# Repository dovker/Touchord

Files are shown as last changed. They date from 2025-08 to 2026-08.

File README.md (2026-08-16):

# Touchord
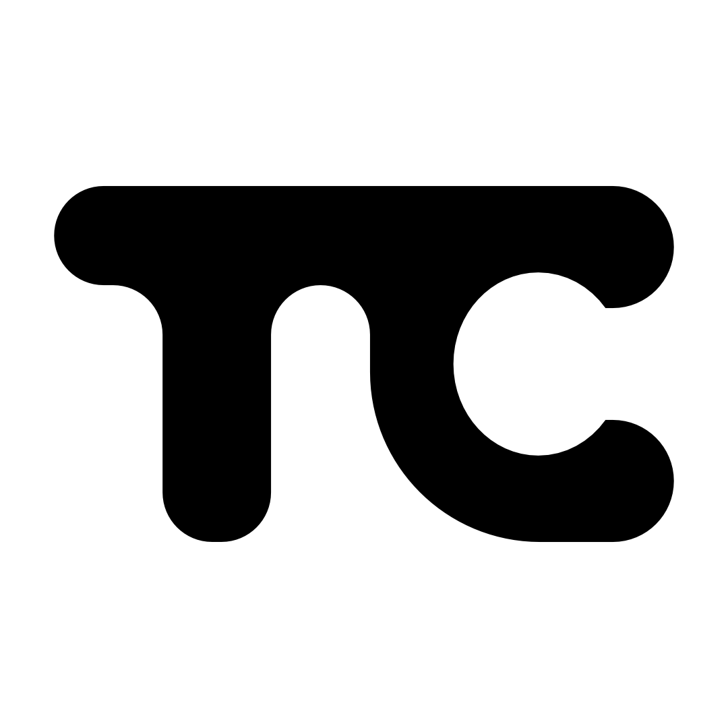
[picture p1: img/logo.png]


Touchord is an open source chord-generating MIDI controller featuring a touch bar interface. It is designed for musicians seeking versatile chordal playing and performance options and for makers looking for a highly modifyable product with a realistic and fun use.

## [TOUCHORD DIY KIT PRE-ORDERS](https://daugdara.com/products/touchord-diy-kit)

## Motivation

Making music without formal training is hard. Learning theory takes time, and when the goal is to create and express ideas quickly, it can feel tedious. Chord progressions and harmony are crucial yet difficult to master; exploring by ear works, but entering complex chords on guitar or piano is slow. That is where chord‑generating synths and MIDI controllers help.

**Why not buy an existing similar device?** Many are closed‑source and built by unestablished companies with limited support histories. When projects are abandoned or parts become unavailable, devices turn into e‑waste.

Touchord addresses these problems. Components are common, 3D‑printable, or manufacturable at a reasonable cost, thus repairs and replacements remain feasible. Open development also streamlines bug fixes and issue tracking because contributors can help accelerate software improvements. And if we for some reason stop developing new updates or cannot contribute anymore, community still remains along with the source code and all the production files, keeping the project alive.

## Licensing and Legal Notice

**Copyright © 2026 MB Daugdara. All rights reserved.**

**Trademarks:**
- Touchord™ is a trademark of MB Daugdara
- Touchord™ logo is a trademark of MB Daugdara

**Intellectual Property:**
- The Touchord name and logo are the exclusive property of MB Daugdara
- Firmware is licensed under GNU General Public License v3.0
- The 3D model design files and PCB Files are licensed under CERN-OHL-S-2.0
- The license does not grant rights to use the company name or logo

**Restrictions:**
- You may not use the company name or logo to endorse derivative commercial works
- You must include this notice when distributing modified versions
- See LICENSE file for full CERN-OHL-S-2.0 terms

## Features

- **Three Operating Modes:**
  - **Strum Mode:** Harp style playing for plucked synths.
  - **Omni Mode:** An omni-chord style play mode mimicking the strumming of an omnichord.
  - **Composer Mode:** Allows adjustment of chord qualities directly via the touch bar for chord customization.
  - **Perform Mode:** Uses the touch bar’s pressure sensitivity for expressive live performances.
  - **Drum Mode:** A simple mode with chromatically mapped keys and the touch bar controlling velocity.

- **Chord Layout:**
  - Each key corresponds to a chord degree in a musical key.
  - Supports custom musical keys and customizable chords on each key.

- **Hardware:**
  - Uses the RP2350 microcontroller chip.
  - Programmed with the PicoSDK in C.
  - Cherry MX style mechanical switches.
  - 6 control buttons.
  - 7 chord keys sized 3u, equipped with 3u plate-mounted stabilizers for enhanced stability.
  - Touch bar: [Trill Bar by Bella](https://bela.io/products/trill/) ([GitHub](https://github.com/BelaPlatform/Trill)) providing multi-touch and pressure sensing.
  - Display: Standard 0.96" 128x64 OLED SSD1306 screen.

- **Enclosure:**
  - Combination of 3D printed carbon fiber reinforced PETG base and CNC machined aluminum top.
  - Optionally, the top can also be fabricated via 3D printing.

- **Connectivity:**
  - USB Type-C MIDI support.
  - TRS MIDI support (User switchable in software):
    - **TRS Type A (Standard MIDI TRS)**
    - **TRS Type B (Roland TRS MIDI)**

---

## Contribution

Check `CONTRIBUTING.md` for more info.

### AI Usage

AI usage on Bug Fixes and Code Auditing is welcome, if done with proper testing, cleanup and no blind trust. Please disclose AI usage in Pull Requests.
Features are better left for humans to write.

---

## Showcase

Showcase video (https://www.youtube.com/watch?v=dFS27xT5Rgg)
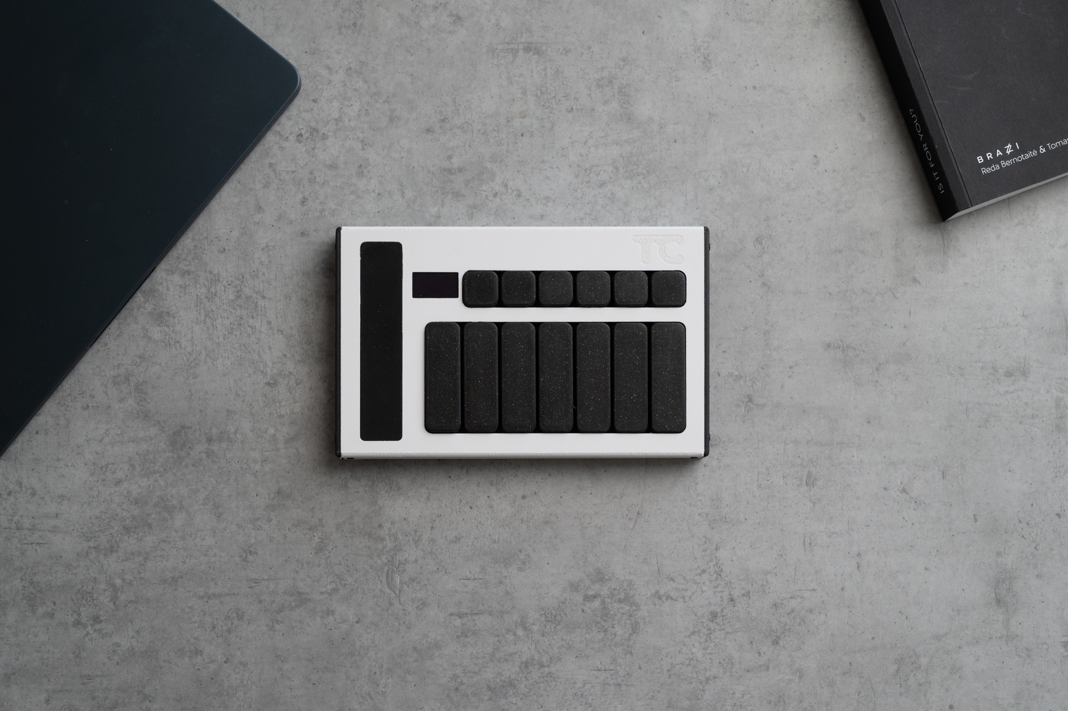
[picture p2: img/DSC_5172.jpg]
Touchord On a grander scale

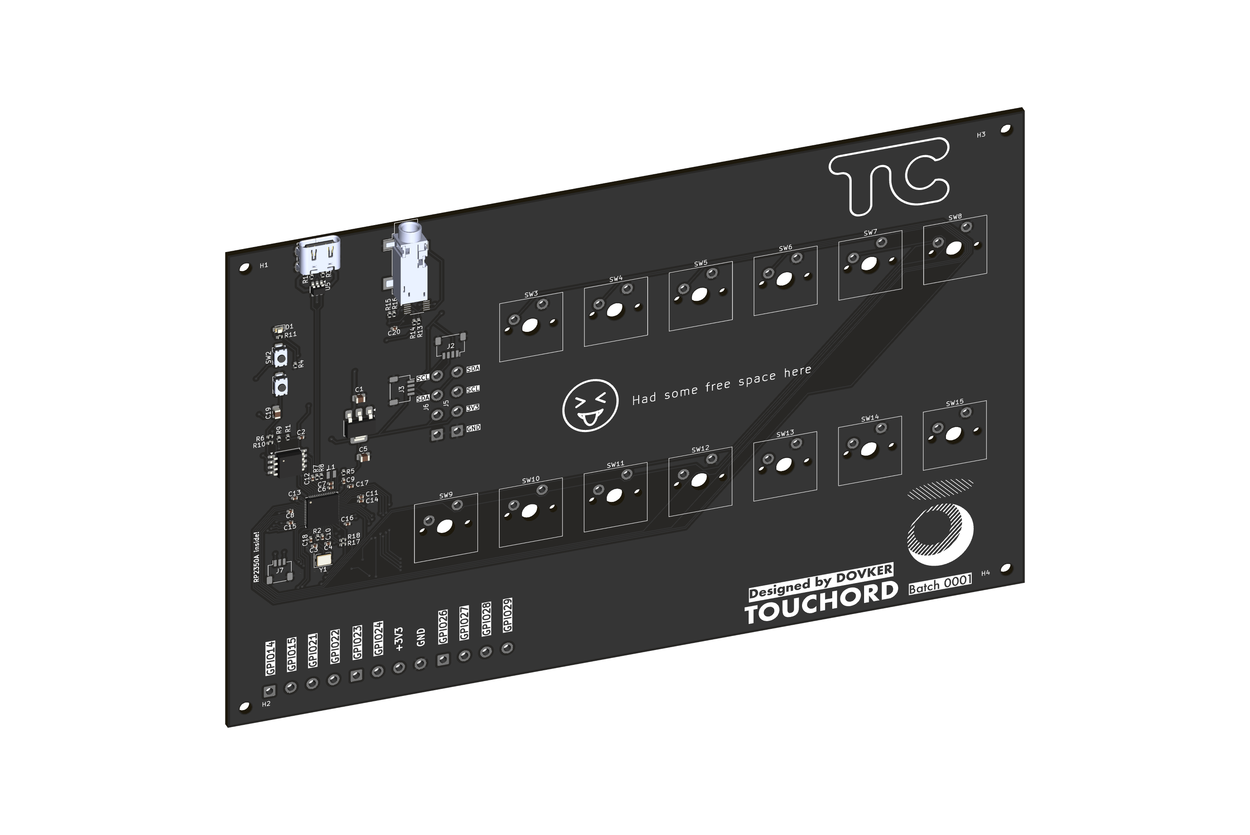
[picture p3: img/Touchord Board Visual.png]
Touchord PCB


## User Showcase
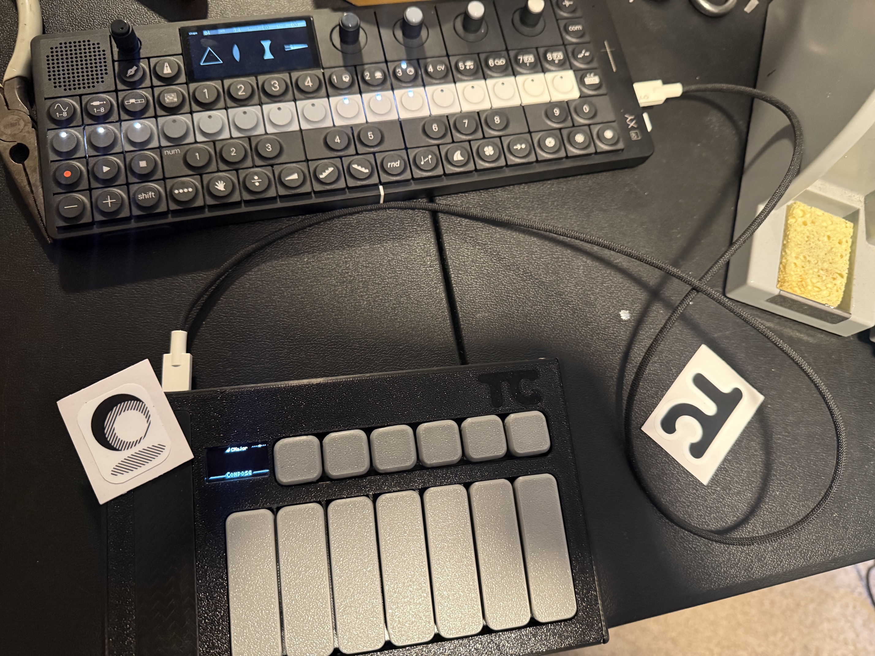
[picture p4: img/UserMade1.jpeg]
User Made Touchord with cool colors


## Projects based on Touchord

### "Ghetto" Touchord made using Pico 2W by [nlpeeee](https://github.com/nlpeeee/TCw)
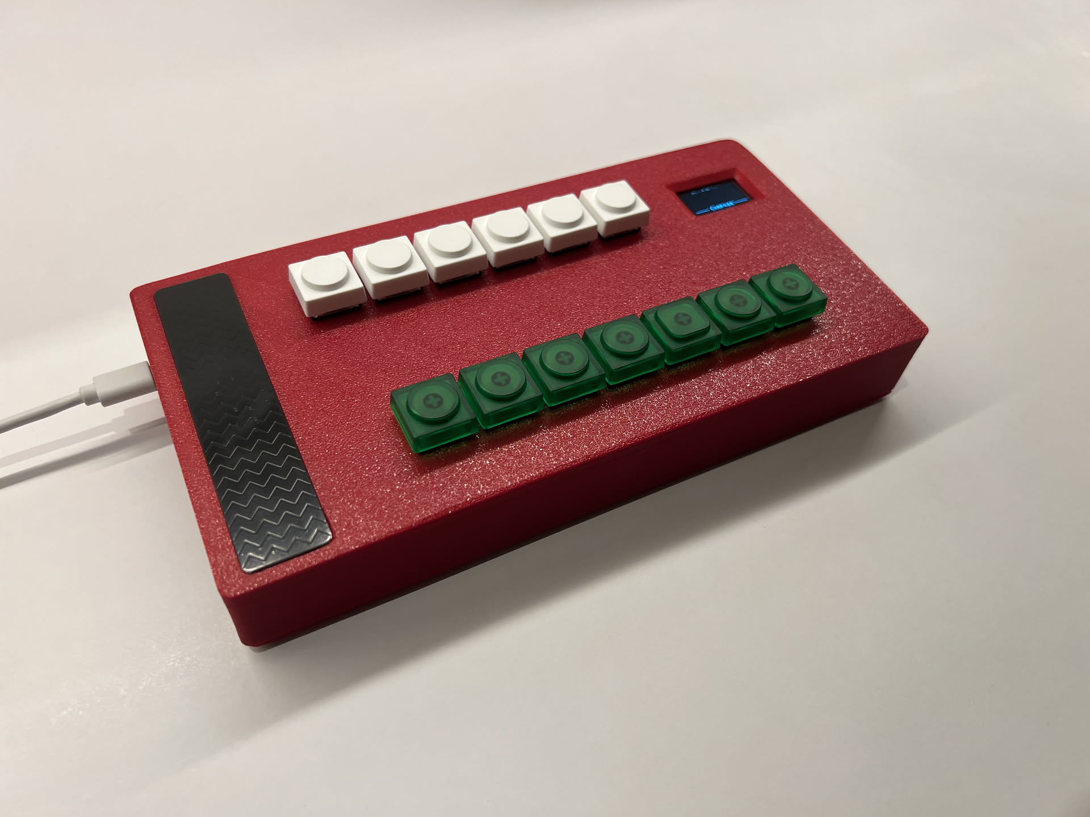
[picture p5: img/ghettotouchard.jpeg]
"Ghetto Touchord"


## Special Thanks

I wanted to share my experience with [PCBWay](https://www.pcbway.com/), as I used it for prototyping and although they have helped me produce one of the batches at their cost, this opinion is my own. My choice to go with PCB Way was first, and only then did I ask for their help.

They have been an amazing experience, especially comparing to their biggest competitors, as for the same price I was able to manufacture boards of way better quality. I couldn't have made this project without PCBA services, as soldering small footprint components are too time consuming and expensive to setup.

What I have found is that the quality of thru-holes, soldering are way better and feel like an actual professional product instead of a draft board. Also, the fact that components can be sourced from anywhere, it doesn't have to be a specific selection of components and other components costing more than a standard price, unlike their competitors. Also, their care of the customer surprised me as I was asked multiple times, whether the components I chose are the right ones (There have been issues with the BOM), and one of the more suprising questions I got was whether the color of soldermask could be changes, as properties of black soldermask wouldn'tve played well with my design. That was amazing, as other service providers just apply blind trust and manufacture the board.

Overall, an amazing experience, especially for anyone looking to prototype PCB's that don't feel like toys, guaranteeing that what you designed will be what you get.

---

*Find the Trill Bar by Bella:* [https://bela.io/products/trill/](https://bela.io/products/trill/)
*Trill Bar GitHub repository:* [https://github.com/bela-platform/trill](https://github.com/BelaPlatform/Trill)

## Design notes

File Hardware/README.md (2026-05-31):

## Licensing and Legal Notice

**Copyright © 2026 MB Daugdara. All rights reserved.**

**Trademarks:**
- Touchord™ is a trademark of MB Daugdara
- Touchord™ logo is a trademark of MB Daugdara

**Intellectual Property:**
- The Touchord name and logo are the exclusive property of MB Daugdara
- Firmware is licensed under GNU General Public License v3.0
- The 3D model design files are licensed under CERN-OHL-S-2.0
- The license does not grant rights to use the company name or logo

**Restrictions:**
- You may not use the company name or logo to endorse derivative commercial works
- You must include this notice when distributing modified versions
- See LICENSE file for full CERN-OHL-S-2.0 terms

# 3D Models

Parametric 3D Models are stored in Enclosure/Parametric folder, containing Fusion 360 Files. 
For those, who prefer not to use Fusion360, parametric models are modifiable in [Makerworld](https://makerworld.com/en/models/2870548-touchord-open-source-midi-controller-shell)

For 3D Printing and custom tolerances Models can be downloaded in [Makerworld](https://makerworld.com/en/models/2870548-touchord-open-source-midi-controller-shell)

STEP Files are in Enclosure folder.

When 3D Printing, adjust tolerances and screw hole sizes accordingly. Recommended orientations:
- Base, flat side on the build plate;
- Top shell, top flat part on the build plate, tree supports (Requires extra removal);
- Keycaps, flat side on the bed;
- Key plates, flat on the bed.

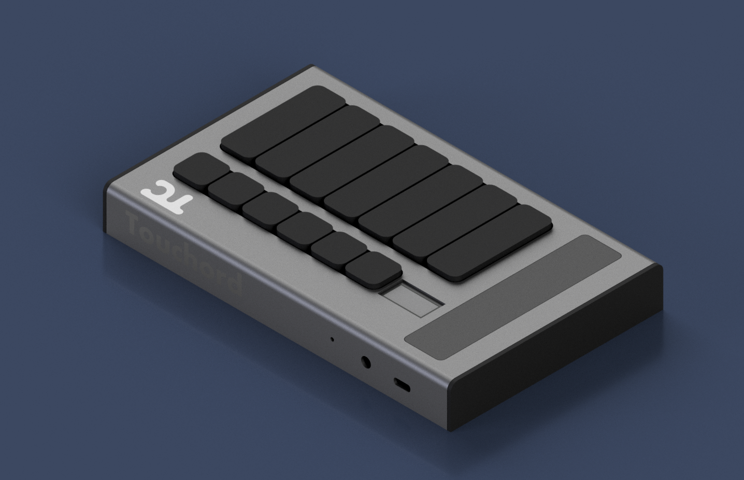
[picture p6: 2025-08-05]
img/TC Render 1.png

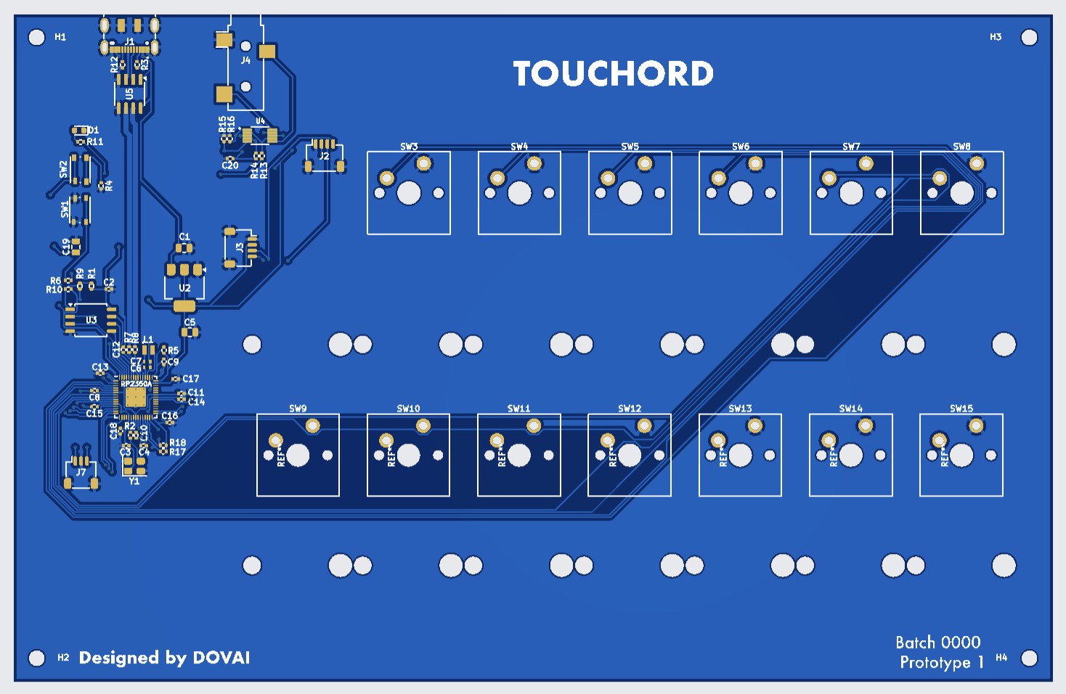
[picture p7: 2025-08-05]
img/PCB.png

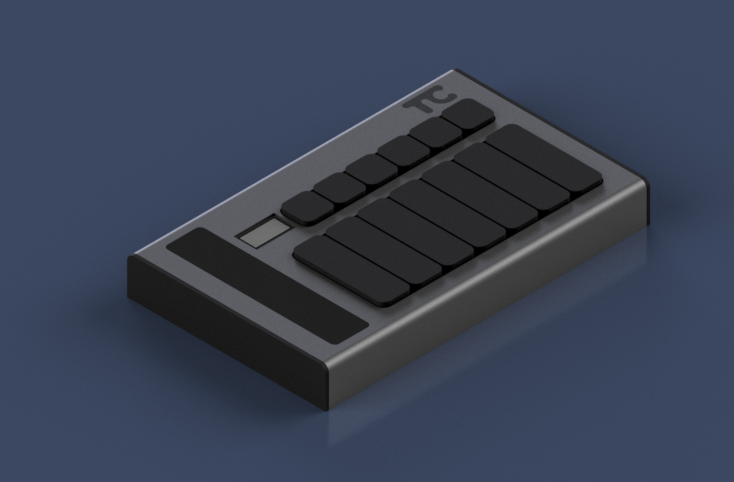
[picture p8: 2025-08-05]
img/TC Render 2.png

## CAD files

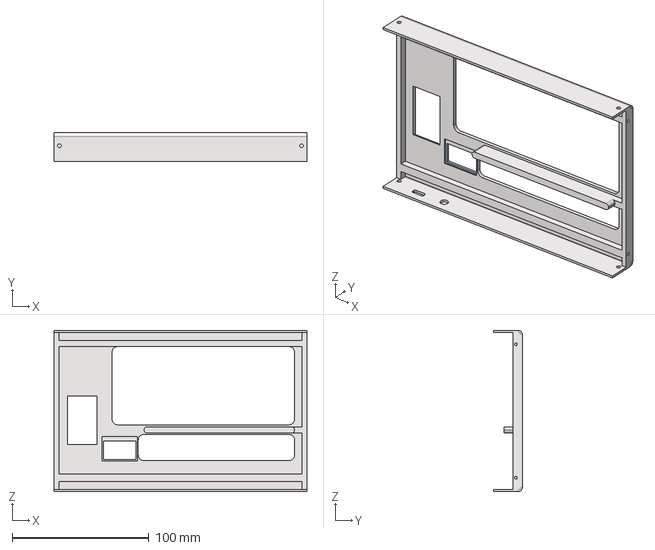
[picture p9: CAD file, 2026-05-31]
Hardware/Enclosure/Top Shell.step
185.0 x 21.0 x 118.0 mm

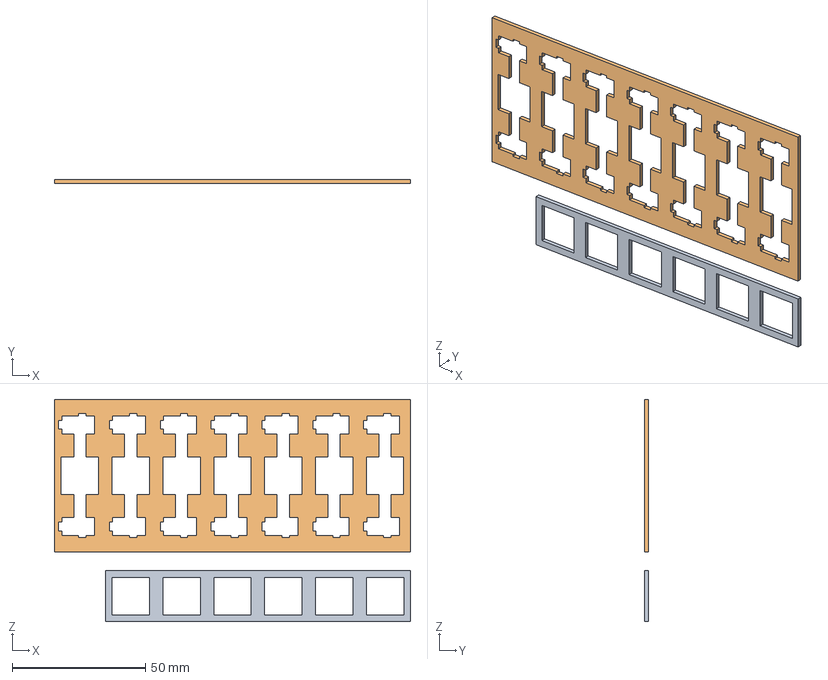
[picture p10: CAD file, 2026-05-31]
Hardware/Enclosure/Key Plates.step
133.4 x 1.50 x 83.3 mm

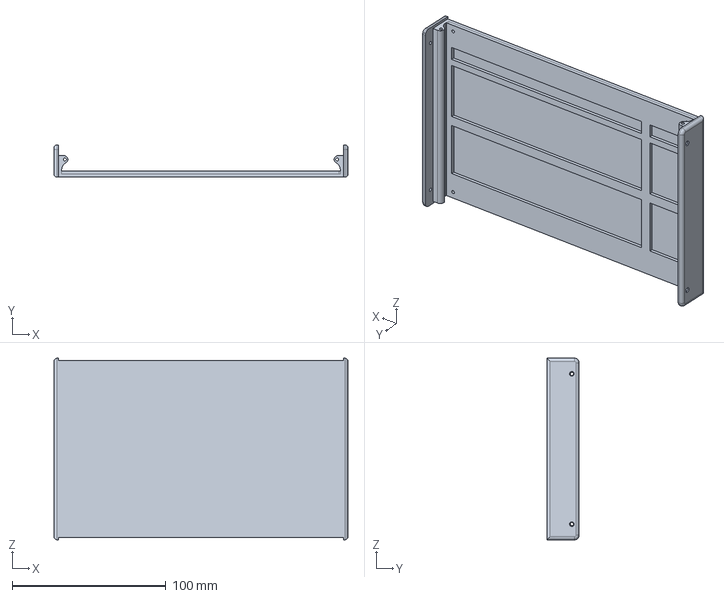
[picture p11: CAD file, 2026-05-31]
Hardware/Enclosure/Base.step
191.0 x 21.0 x 118.0 mm

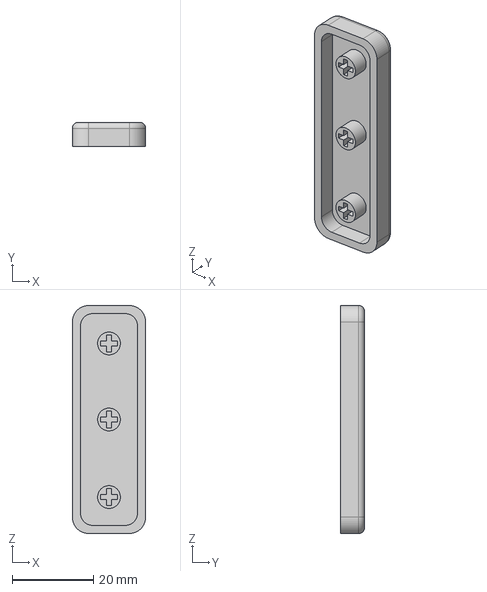
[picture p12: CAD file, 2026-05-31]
Hardware/Enclosure/3U Keycap.step
18.0 x 6.00 x 56.0 mm

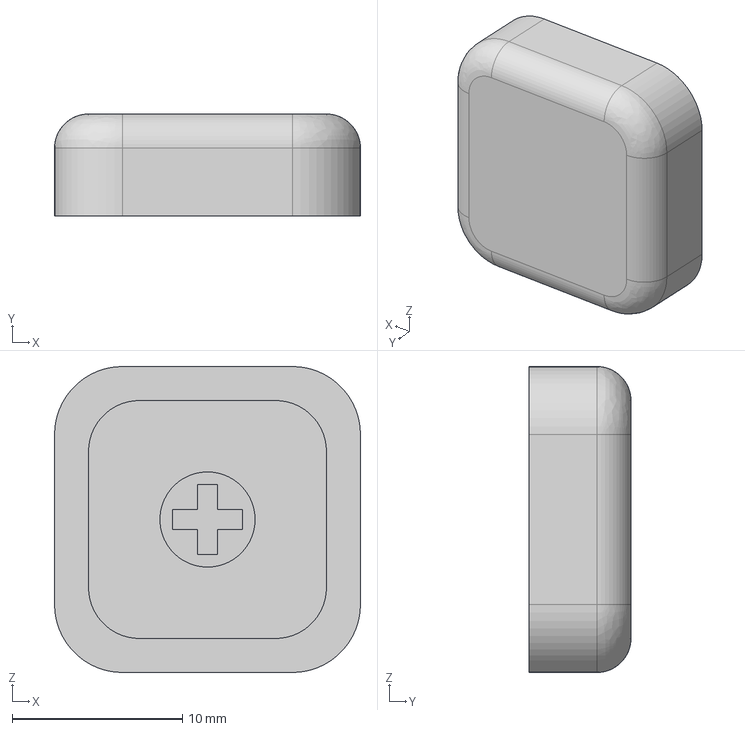
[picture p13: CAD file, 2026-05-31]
Hardware/Enclosure/1U Keycap.step
18.0 x 6.00 x 18.0 mm

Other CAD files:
Hardware/Enclosure/Parametric/Parametric 1U Keycap.f3d
Hardware/Enclosure/Parametric/Parametric 3U Keycap.f3d
Hardware/Enclosure/Parametric/Parametric Base.f3d
Hardware/Enclosure/Parametric/Parametric Top Shell.f3d

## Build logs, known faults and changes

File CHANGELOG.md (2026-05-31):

# Changelog

All notable changes to Touchord are recorded here.

The format follows [Keep a Changelog](https://keepachangelog.com/en/1.1.0/),
and this project adheres to [Semantic Versioning](https://semver.org/spec/v2.0.0.html).

The single source of truth for the firmware version is `src/version.h`. CMake
parses it so build artifacts and `pico_set_program_version()` stay in lockstep
with what the firmware reports at runtime. Bump it together with this file
when cutting a release.

## [Unreleased]

### Added

### Changed

### Fixed

### Removed

## [1.0.0] — 2026-05-31

### Added

- Compose Jazz mode (tritone sub, secondary dominant, parallel maj↔min, vii°7).
- Compose voice-leading toggle.
- Compose trill tooltip.
- Drum mode and visual 7-pad grid.
- Trill bar position indicator.
- Transitions between modes.
- Boot Intro.
- Octave / range visuals.
- Settings page.
- Dual-I2C and single-I2C firmware.
- Persistent presets.
- Custom scales: four user-configurable scale slots.
- Compose sustain toggle, Perform CC mappings/defaults/reset-on-lift toggles.
- Versioning system: `src/version.h`.
- `CONTRIBUTING.md` developer guide (architecture, concurrency, mode/setting how-tos, pitfalls, PR + release flow).
- SPDX copyright header (`Copyright (C) 2025-2026 MB Daugdara`, `GPL-3.0-or-later`, `info@daugdara.com`) on every non-vendored source file.
- DMA-based screen send.
- Other features.

### Changed

- `compose_key_down` snapshots and emits set-difference (no transient natural chord when pressing a key with the bar held in JAZZ).
- `compose_trill_down` updates trill state and tooltip outside the chord-name guard so the bar's effect is in place when a key press arrives.
- `io_task` polls the trill 5× per frame so latency drops from ~30 ms to a few ms.
- Screen I2C bumped to 1 MHz.
- `tc_app_default` now uses designated initialisers — adding fields can't silently misalign the list.
- Trill 4 % deadzone.
- `io_task` calls `multicore_lockout_victim_init()` so `flash_save_preset` can pause it without hanging.
- `trill_init` now requests 16-bit resolution to match the `TRILL_MAX_SIZE` normalisation.
- Other changes.

### Fixed

- Too many to track for initial release.

### Removed

- Legacy single-frame `main()` splash (replaced by `anim_boot_intro`).
- USB CDC settings protocol.

[Unreleased]: https://github.com/dovker/Touchord/compare/v1.0.0...HEAD
[1.0.0]: https://github.com/dovker/Touchord/releases/tag/v1.0.0

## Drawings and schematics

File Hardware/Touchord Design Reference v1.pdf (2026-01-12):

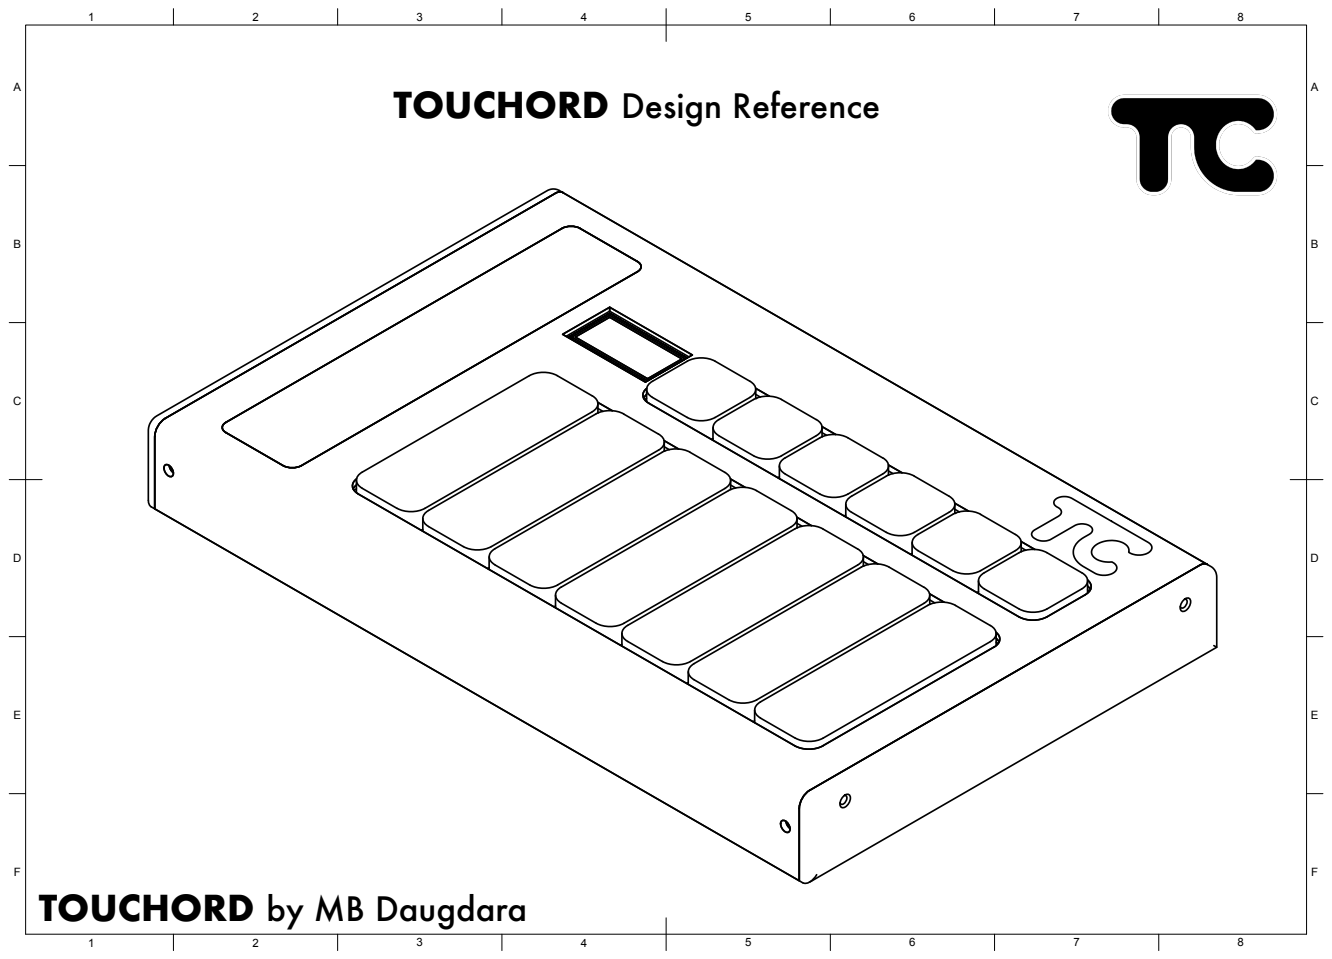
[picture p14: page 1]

TOUCHORD Design Reference

TOUCHORD by MB Daugdara

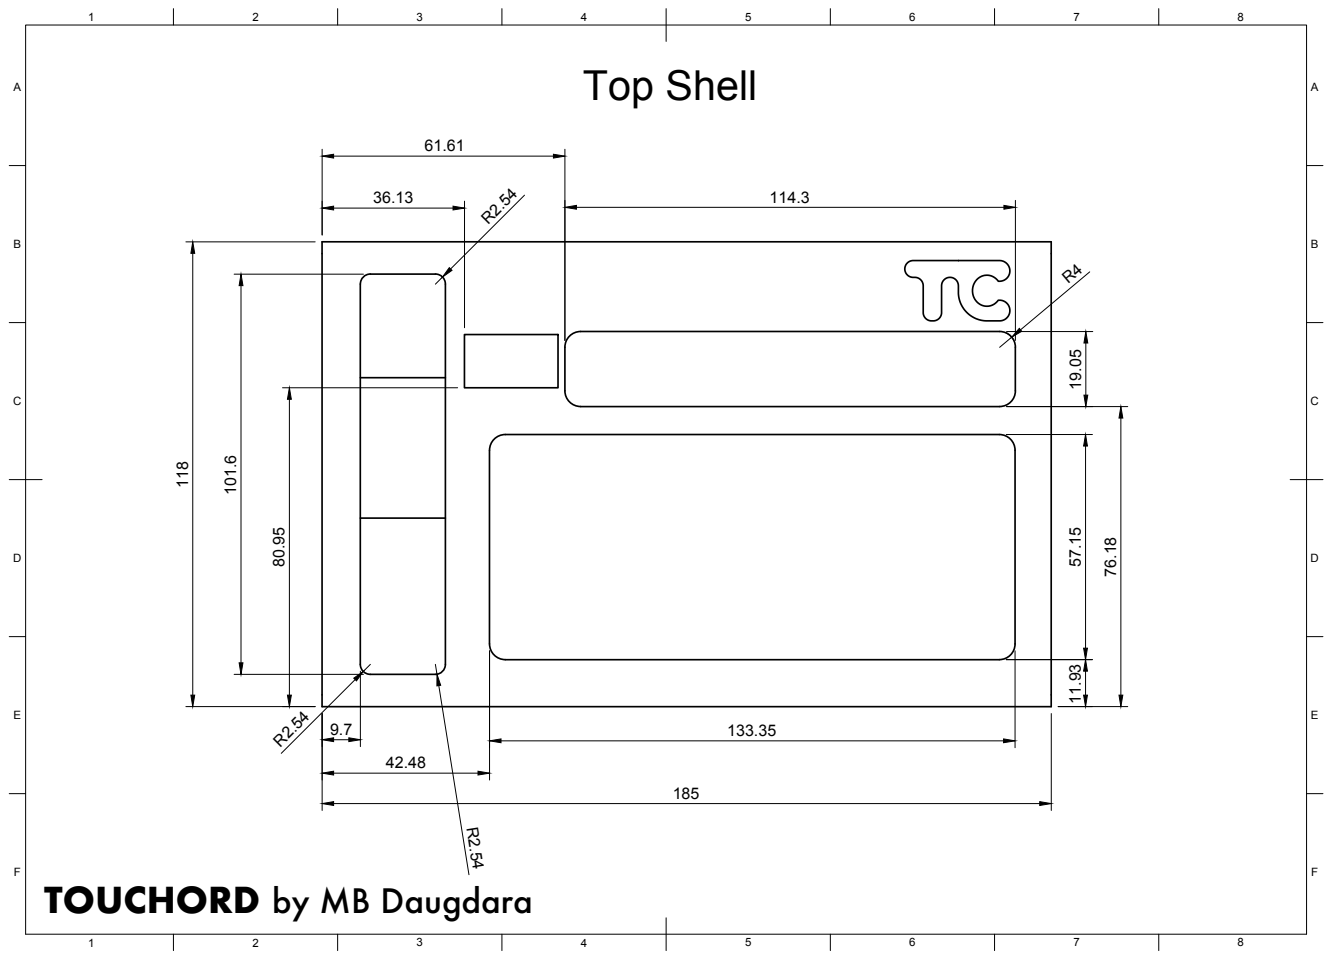
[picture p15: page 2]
Top Shell

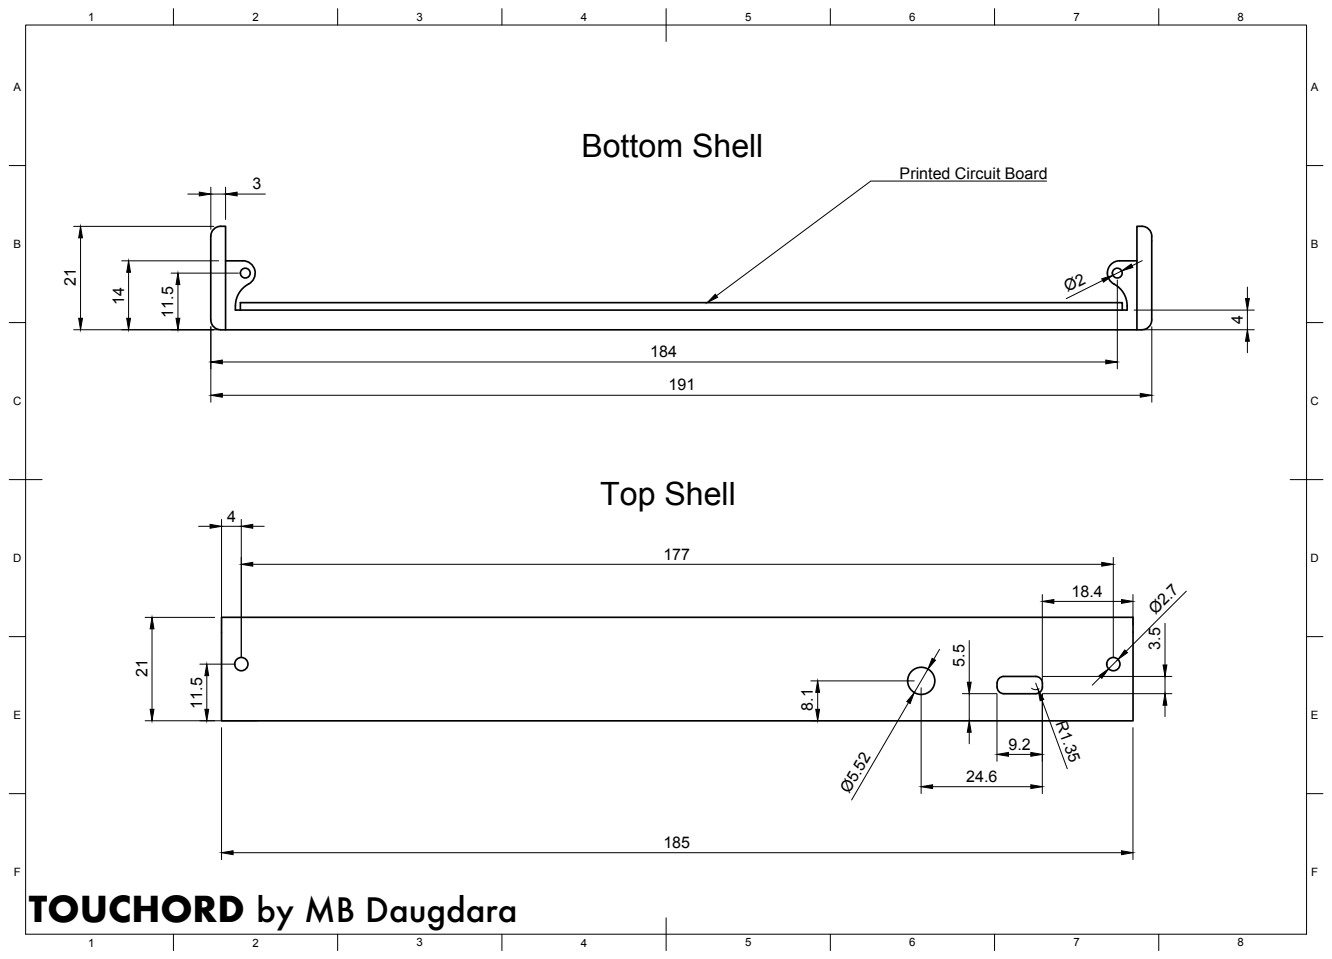
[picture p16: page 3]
Bottom Shell; Top Shell

Printed Circuit Board

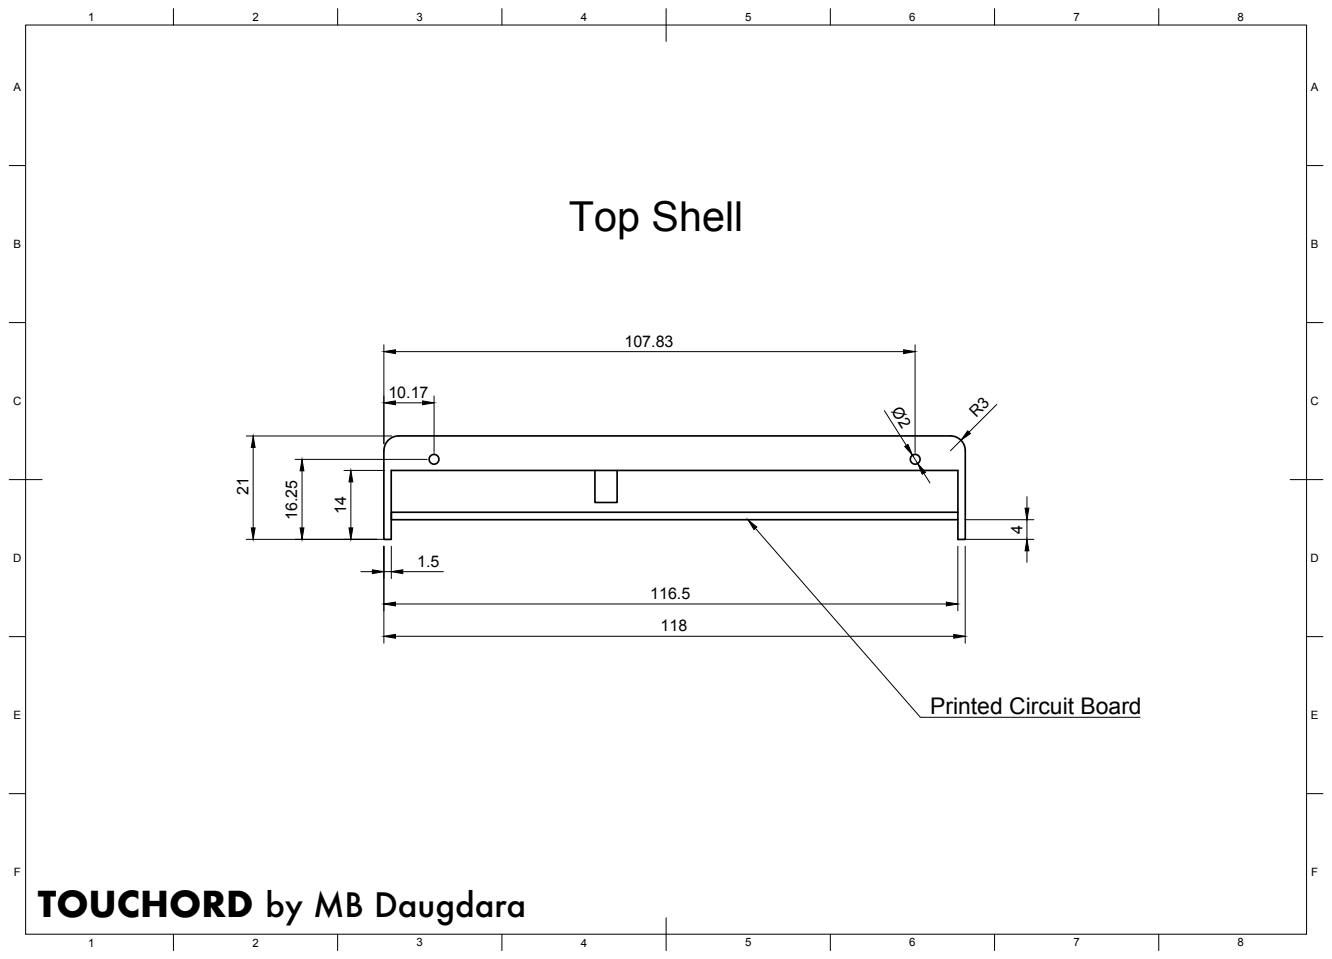
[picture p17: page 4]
Top Shell

Printed Circuit Board

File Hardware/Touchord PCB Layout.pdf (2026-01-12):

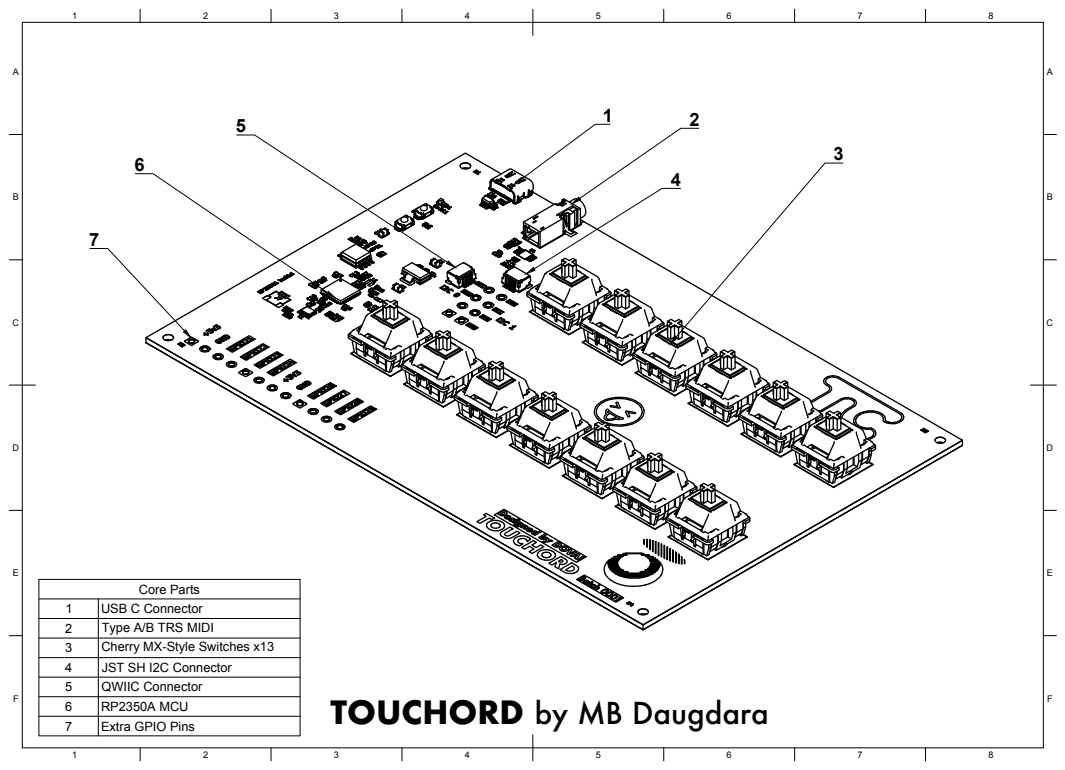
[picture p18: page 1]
Core Parts; USB C Connector; Type A/B TRS MIDI; Cherry MX-Style Switches x13; JST SH I2C Connector; QWIIC Connector; RP2350A MCU; Extra GPIO Pins

TOUCHORD by MB Daugdara

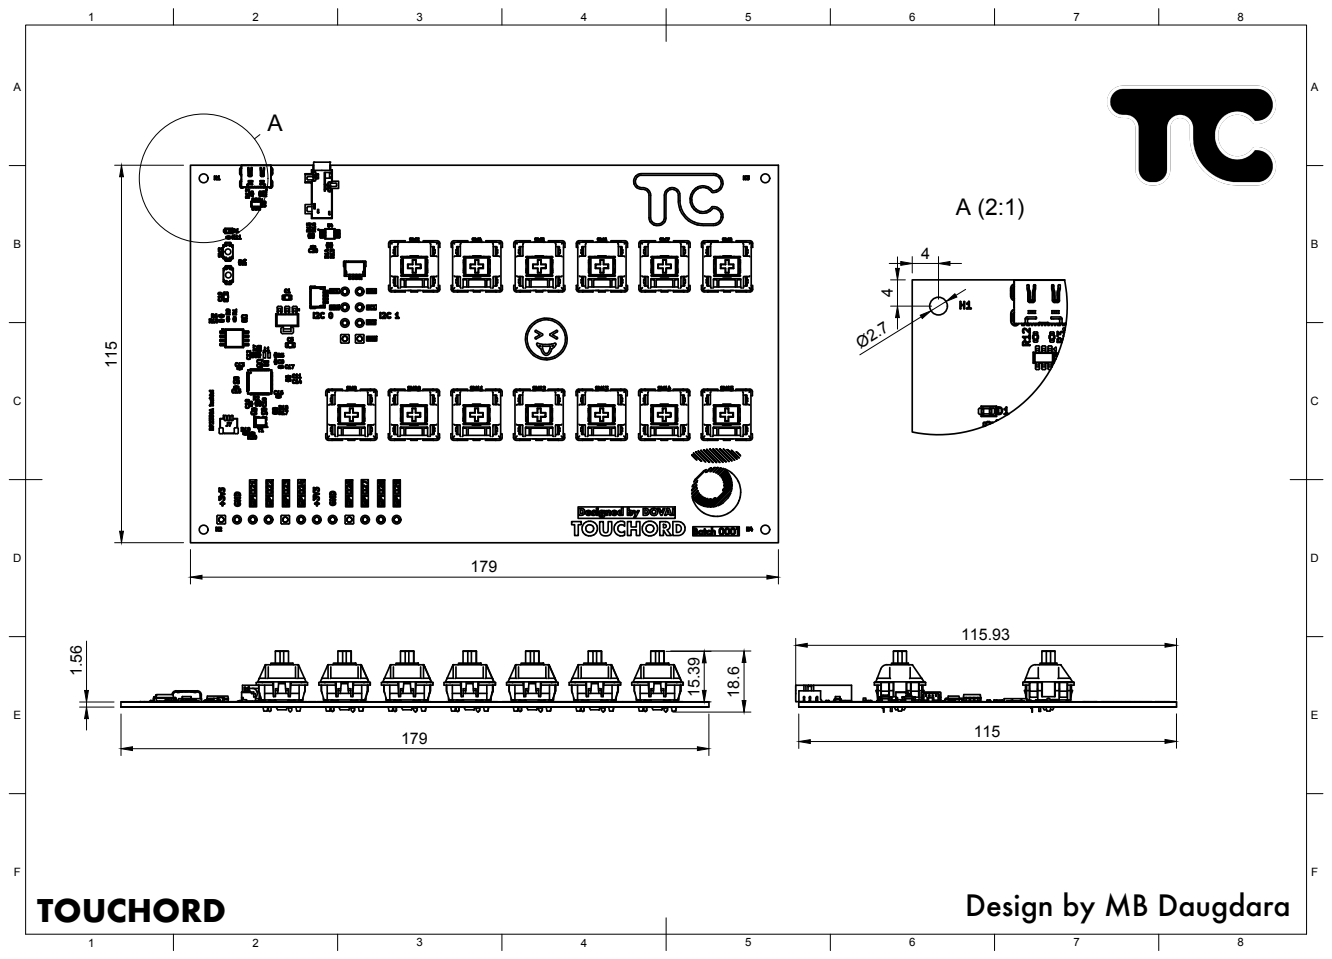
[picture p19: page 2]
TOUCHORD; Design by MB Daugdara

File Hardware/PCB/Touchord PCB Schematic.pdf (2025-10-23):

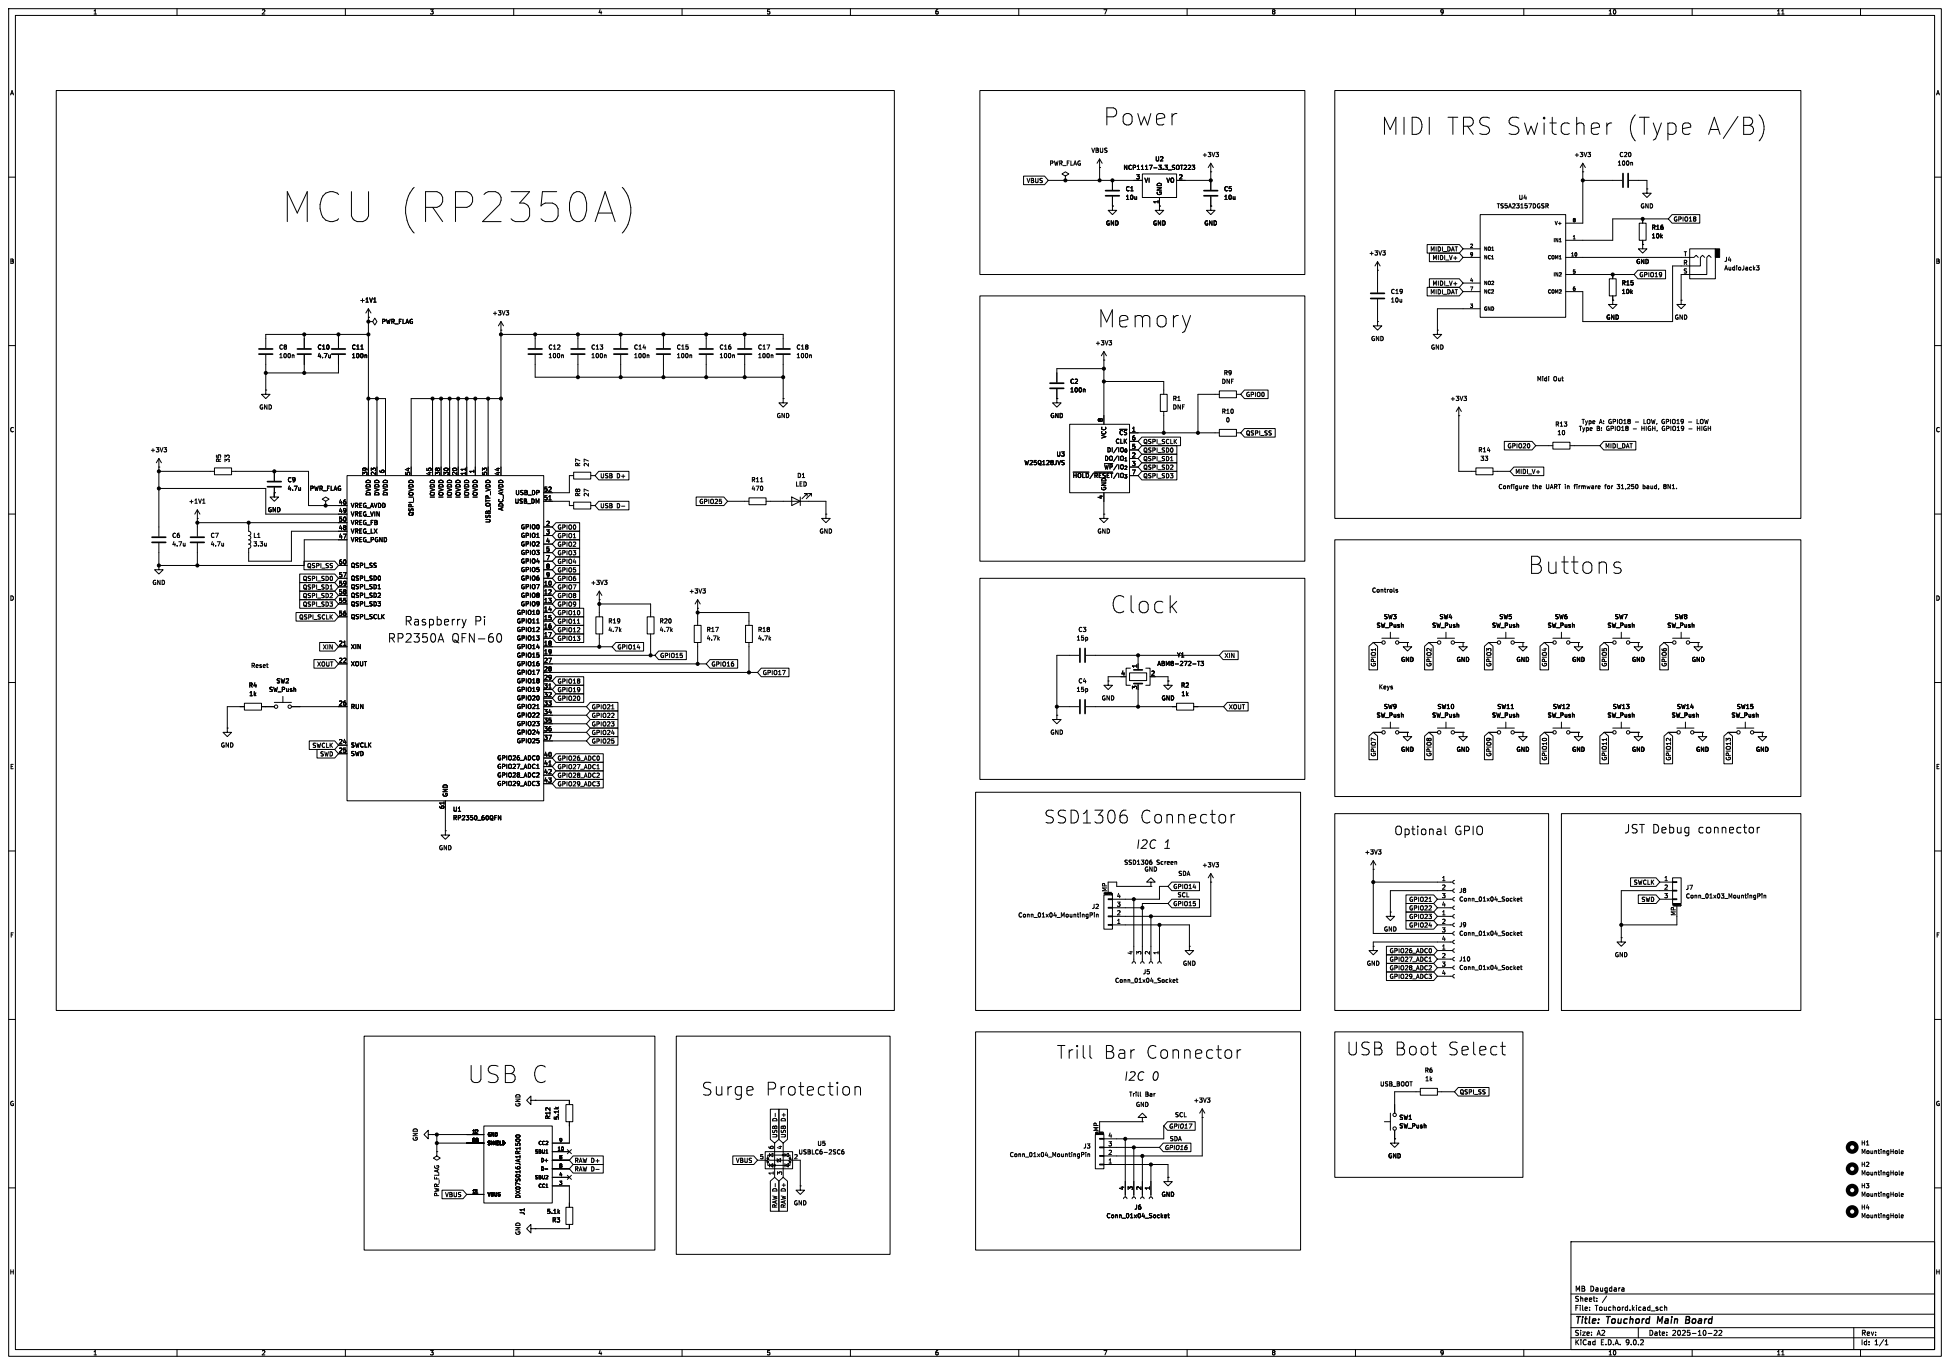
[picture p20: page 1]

MIDI TRS Switcher (Type A/B)

~{CS}1 CLK 6 DI/IO_{0}5 DO/IO_{1}2 ~{WP}/IO_{2} 3 ~{HOLD}/~{RESET}/IO_{3} 7 VCC 8 GND 4 C2

Type B: GPIO18 - HIGH, GPIO19 - HIGH Buttons

H4 MountingHole H3 MountingHole H1 MountingHole H2 MountingHole

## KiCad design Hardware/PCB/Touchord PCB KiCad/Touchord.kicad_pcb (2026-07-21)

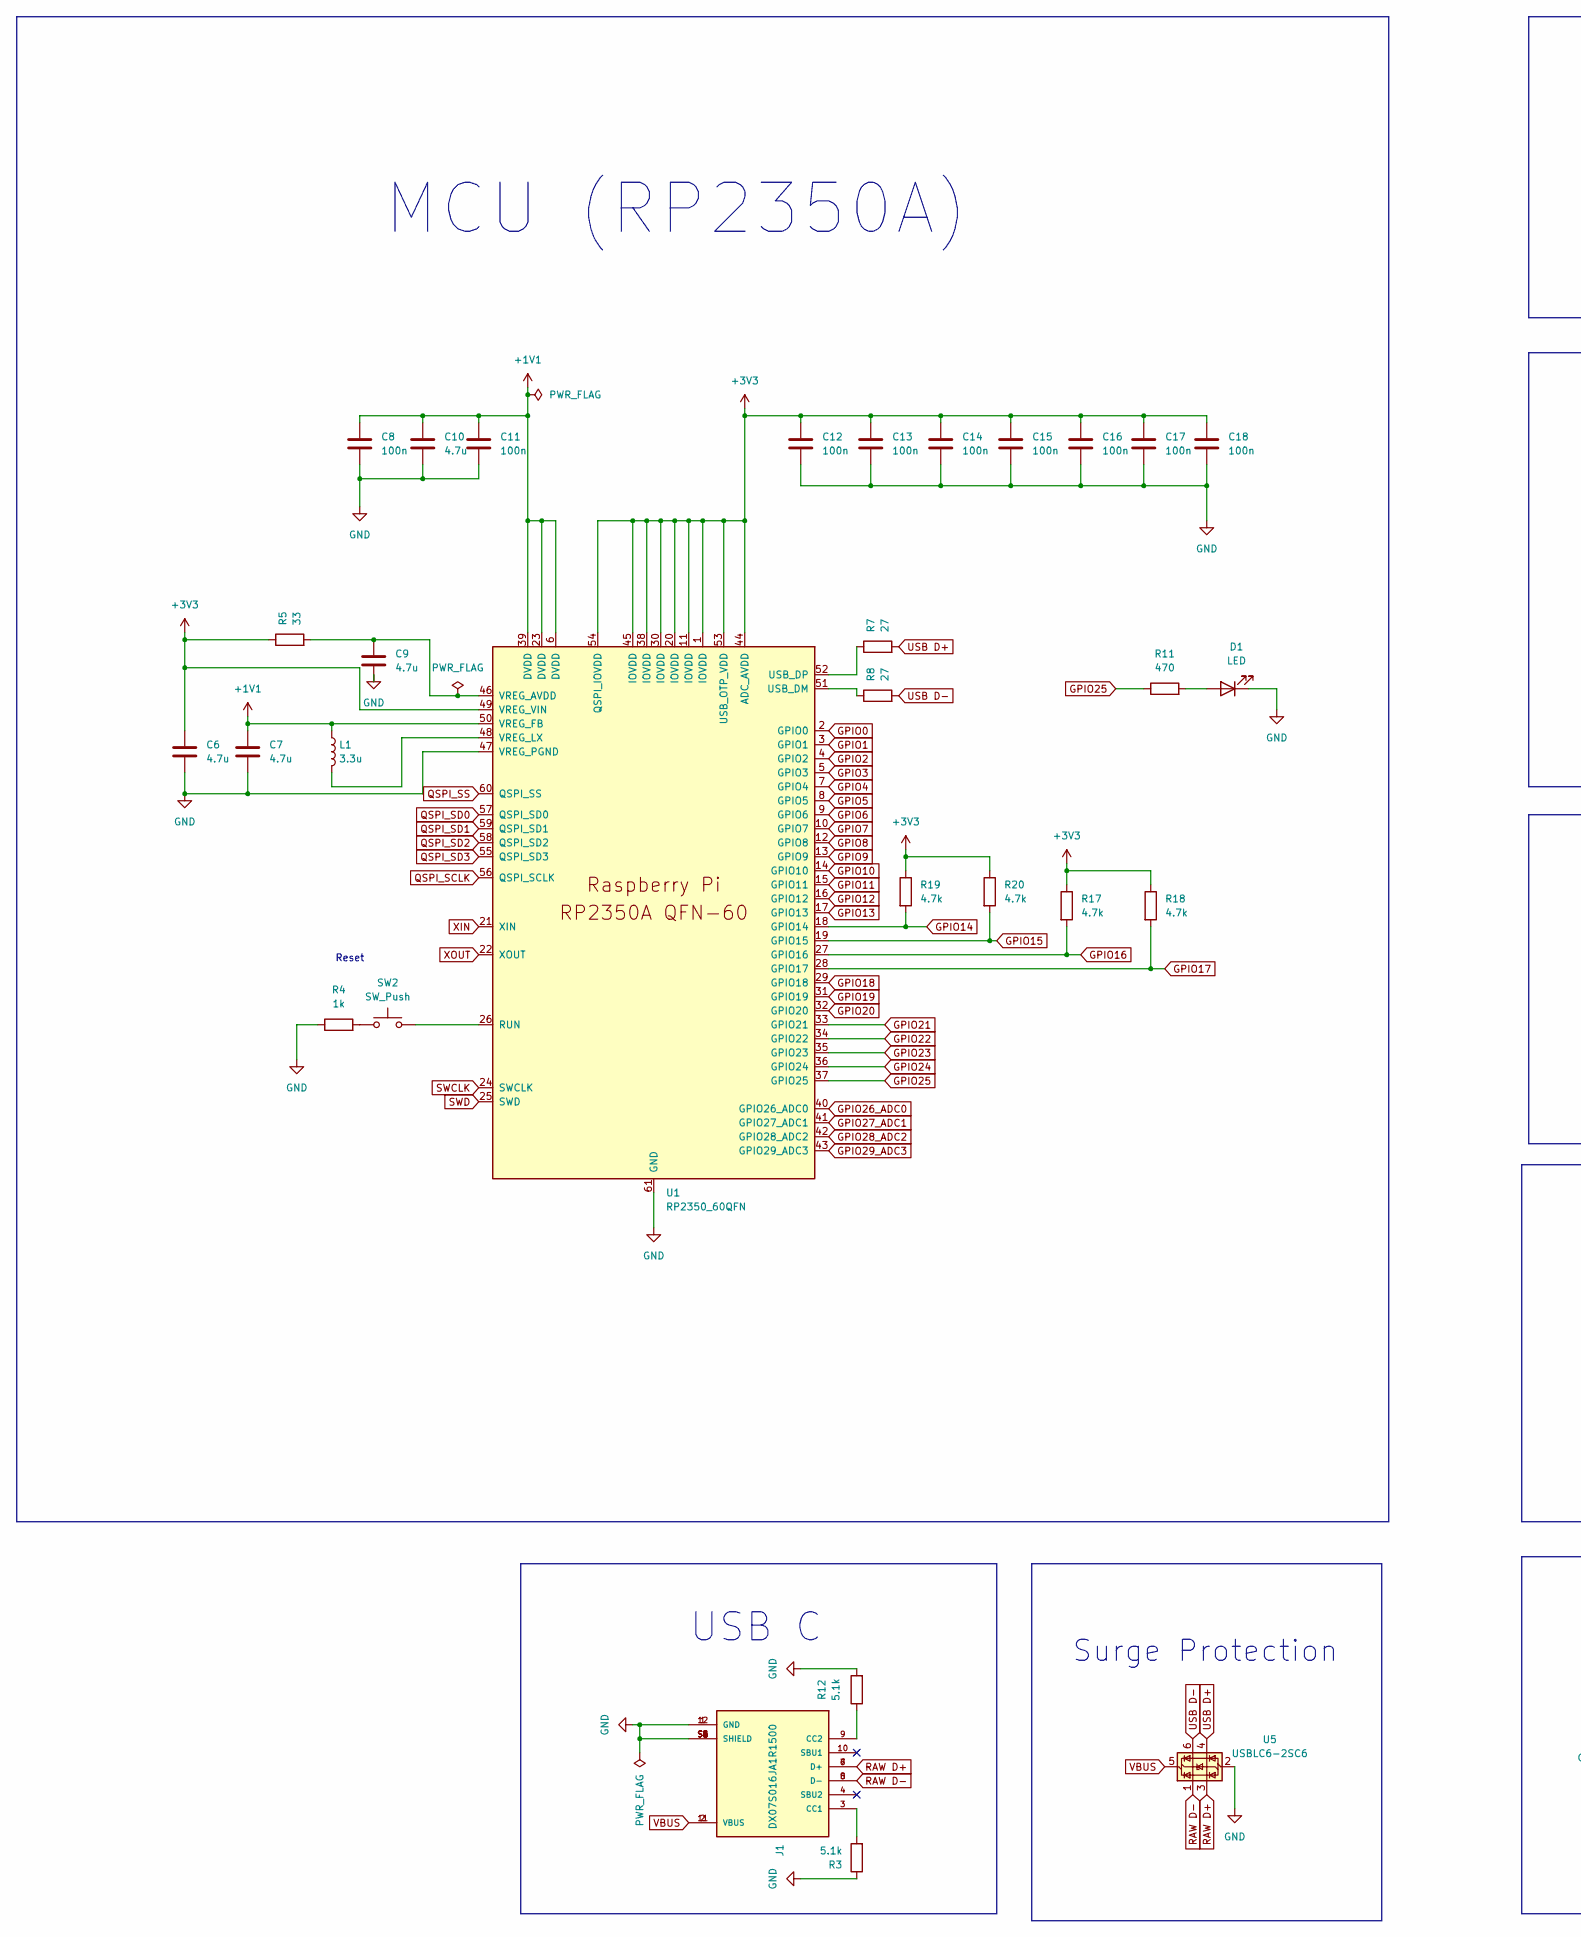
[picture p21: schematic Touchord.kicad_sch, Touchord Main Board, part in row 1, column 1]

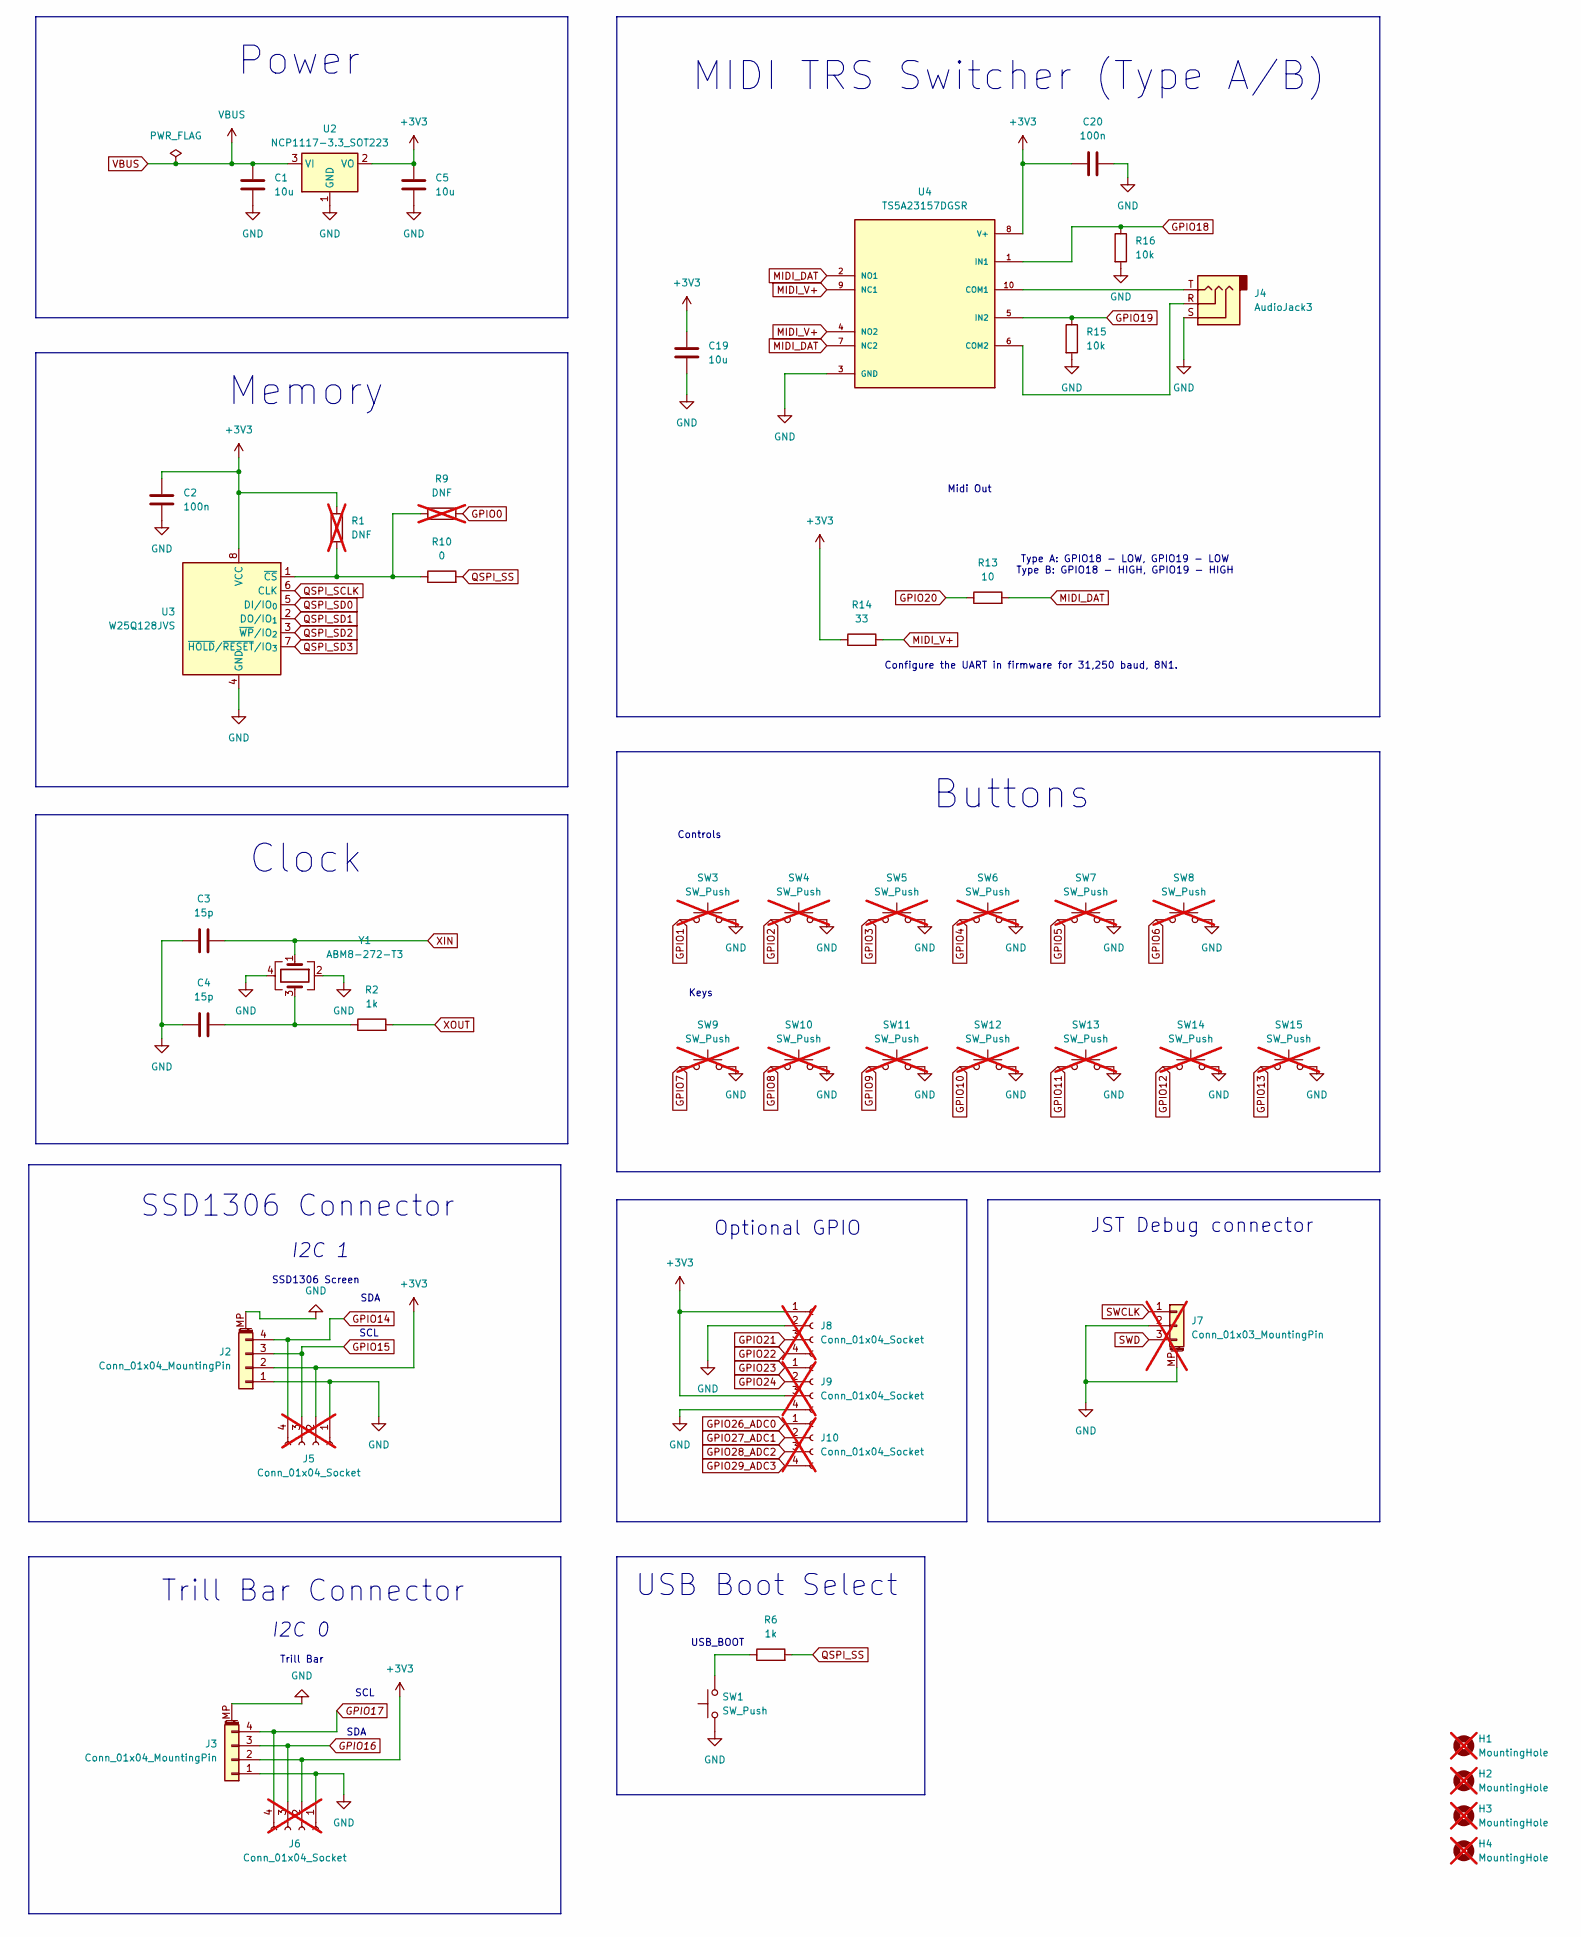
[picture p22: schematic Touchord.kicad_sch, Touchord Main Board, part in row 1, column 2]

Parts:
C1, C5, C19: 10u; C_0805_2012Metric
C2, C8, C11, C12, C13, C14, C15, C16, C17, C18, C20: 100n; C_0402_1005Metric
C3, C4: 15p; C_0402_1005Metric
C6, C7: 4.7u; C_0402_1005Metric_small_pads
C9, C10: 4.7u; C_0402_1005Metric
D1: LED; LED_0603_1608Metric
H1, H2, H3, H4: MountingHole; MountingHole_2.7mm_M2.5; not fitted
J1: DX07S016JA1R1500; JAE_DX07S016JA1R1500; PARTREV 1
J2, J3: Conn_01x04_MountingPin; JST_SH_SM04B-SRSS-TB_1x04-1MP_P1.00mm_Horizontal
J4: AudioJack3; Jack_3.5mm_CUI_SJ-3523-SMT_Horizontal
J5, J6, J8, J9, J10: Conn_01x04_Socket; SolderWire-0.75sqmm_1x04_P4.8mm_D1.25mm_OD2.3mm; not fitted
J7: Conn_01x03_MountingPin; JST_SH_SM03B-SRSS-TB_1x03-1MP_P1.00mm_Horizontal; not fitted
L1: 3.3u; L_pol_2016
R1, R9: DNF; R_0402_1005Metric; not fitted
R2, R4, R6: 1k; R_0402_1005Metric
R3, R12: 5.1k; R_0402_1005Metric
R5, R14: 33; R_0402_1005Metric
R7, R8: 27; R_0402_1005Metric
R10: 0; R_0402_1005Metric
R11: 470; R_0402_1005Metric
R13: 10; R_0402_1005Metric
R15, R16: 10k; R_0402_1005Metric
R17, R18, R19, R20: 4.7k; R_0402_1005Metric
SW1, SW2: SW_Push; SW_TS-1088-AR02016
SW3, SW4, SW5, SW6, SW7, SW8: SW_Push; SW_Cherry_MX_PCB_1.00u; not fitted
SW9, SW10, SW11, SW12, SW13, SW14, SW15: SW_Push; SW_Cherry_MX_PCB_3.00u_90deg; not fitted
U1: RP2350_60QFN; RP2350-QFN-60-1EP_7x7_P0.4mm_EP3.4x3.4mm_ThermalVias
U2: NCP1117-3.3_SOT223; SOT-223-3_TabPin2
U3: W25Q128JVS; SOIC-8_5.3x5.3mm_P1.27mm
U4: TS5A23157DGSR; SOP50P490X110-10N; PARTREV F
U5: USBLC6-2SC6; SOT-23-6
Y1: ABM8-272-T3; Crystal_SMD_3225-4Pin_3.2x2.5mm

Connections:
+1V1: C7.1, C8.1, C10.1, C11.1, L1.1, U1.6 (DVDD), U1.23 (DVDD), U1.39 (DVDD), U1.50 (VREG_FB)
+3V3: C2.1, C5.1, C6.1, C12.1, C13.1, C14.1, C15.1, C16.1, C17.1, C18.1, C19.1, C20.1, J2.2, J3.2, J5.2, J6.2, J8.1, J9.3, R1.1, R5.1, R14.1, R17.1, R18.1, R19.1, R20.1, U1.1 (IOVDD), U1.11 (IOVDD), U1.20 (IOVDD), U1.30 (IOVDD), U1.38 (IOVDD), U1.44 (ADC_AVDD), U1.45 (IOVDD), U1.49 (VREG_VIN), U1.53 (USB_OTP_VDD), U1.54 (QSPI_IOVDD), U2.2 (VO), U3.8 (VCC), U4.8 (V+)
GND: C1.2, C2.2, C3.1, C4.1, C5.2, C6.2, C7.2, C8.2, C9.2, C10.2, C11.2, C12.2, C13.2, C14.2, C15.2, C16.2, C17.2, C18.2, C19.2, C20.2, D1.1 (K), J1.1 (GND), J1.12 (GND), J1.S1 (SHIELD), J1.S2 (SHIELD), J1.S3 (SHIELD), J1.S4 (SHIELD), J1.S5 (SHIELD), J1.S6 (SHIELD), J2.1, J2.MP (MountPin), J3.1, J3.MP (MountPin), J4.S, J5.1, J6.1, J7.2, J7.MP (MountPin), J8.2, J9.4, R3.1, R4.1, R12.2, R15.2, R16.2, SW1.1, SW3.2, SW4.2, SW5.2, SW6.2, SW7.2, SW8.2, SW9.2, SW10.2, SW11.2, SW12.2, SW13.2, SW14.2, SW15.2, U1.47 (VREG_PGND), U1.61 (GND), U2.1 (GND), U3.4 (GND), U4.3 (GND), U5.2 (GND), Y1.2, Y1.4
GPIO0: R9.1, U1.2 (GPIO0)
GPIO1: SW3.1, U1.3 (GPIO1)
GPIO2: SW4.1, U1.4 (GPIO2)
GPIO3: SW5.1, U1.5 (GPIO3)
GPIO4: SW6.1, U1.7 (GPIO4)
GPIO5: SW7.1, U1.8 (GPIO5)
GPIO6: SW8.1, U1.9 (GPIO6)
GPIO7: SW9.1, U1.10 (GPIO7)
GPIO8: SW10.1, U1.12 (GPIO8)
GPIO9: SW11.1, U1.13 (GPIO9)
GPIO10: SW12.1, U1.14 (GPIO10)
GPIO11: SW13.1, U1.15 (GPIO11)
GPIO12: SW14.1, U1.16 (GPIO12)
GPIO13: SW15.1, U1.17 (GPIO13)
GPIO14: J2.4, J5.4, R19.2, U1.18 (GPIO14)
GPIO15: J2.3, J5.3, R20.2, U1.19 (GPIO15)
GPIO16: J3.3, J6.3, R17.2, U1.27 (GPIO16)
GPIO17: J3.4, J6.4, R18.2, U1.28 (GPIO17)
GPIO18: R16.1, U1.29 (GPIO18), U4.1 (IN1)
GPIO19: R15.1, U1.31 (GPIO19), U4.5 (IN2)
GPIO20: R13.1, U1.32 (GPIO20)
GPIO21: J8.3, U1.33 (GPIO21)
GPIO22: J8.4, U1.34 (GPIO22)
GPIO23: J9.1, U1.35 (GPIO23)
GPIO24: J9.2, U1.36 (GPIO24)
GPIO25: R11.1, U1.37 (GPIO25)
GPIO26_ADC0: J10.1, U1.40 (GPIO26_ADC0)
GPIO27_ADC1: J10.2, U1.41 (GPIO27_ADC1)
GPIO28_ADC2: J10.3, U1.42 (GPIO28_ADC2)
GPIO29_ADC3: J10.4, U1.43 (GPIO29_ADC3)
MIDI_DAT: R13.2, U4.2 (NO1), U4.7 (NC2)
MIDI_V+: R14.2, U4.4 (NO2), U4.9 (NC1)
unnamed: C4.2, R2.1, Y1.3
unnamed: D1.2 (A), R11.2
unnamed: J1.3 (CC1), R3.2
unnamed: J1.9 (CC2), R12.1
unnamed: R4.2, SW2.1
unnamed: R6.1, SW1.2
unnamed: SW2.2, U1.26 (RUN)
unnamed: R8.1, U1.51 (USB_DM)
unnamed: R7.1, U1.52 (USB_DP)
unnamed: C9.1, R5.2, U1.46 (VREG_AVDD)
unnamed: L1.2, U1.48 (VREG_LX)
unnamed: R1.2, R9.2, R10.1, U3.1 (~CS)
unnamed: J4.T, U4.10 (COM1)
unnamed: J4.R, U4.6 (COM2)
QSPI_SCLK: U1.56 (QSPI_SCLK), U3.6 (CLK)
QSPI_SD0: U1.57 (QSPI_SD0), U3.5 (DI/IO_{0})
QSPI_SD1: U1.59 (QSPI_SD1), U3.2 (DO/IO_{1})
QSPI_SD2: U1.58 (QSPI_SD2), U3.3 (~WP/IO_{2})
QSPI_SD3: U1.55 (QSPI_SD3), U3.7 (~HOLD/~RESET/IO_{3})
QSPI_SS: R6.2, R10.2, U1.60 (QSPI_SS)
RAW D+: J1.6 (D+), J1.7 (D+), U5.3 (I/O2)
RAW D-: J1.5 (D-), J1.8 (D-), U5.1 (I/O1)
SWCLK: J7.1, U1.24 (SWCLK)
SWD: J7.3, U1.25 (SWD)
USB D+: R7.2, U5.4 (I/O2)
USB D-: R8.2, U5.6 (I/O1)
VBUS: C1.1, J1.2 (VBUS), J1.11 (VBUS), U2.3 (VI), U5.5 (VBUS)
XIN: C3.2, U1.21 (XIN), Y1.1
XOUT: R2.2, U1.22 (XOUT)

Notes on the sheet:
I2C 1
Controls
MCU (RP2350A)
Surge Protection
SSD1306 Connector
JST Debug connector
USB_BOOT
Midi Out
Keys
Type A: GPIO18 - LOW, GPIO19 - LOW Type B: GPIO18 - HIGH, GPIO19 - HIGH
SSD1306 Screen
MIDI TRS Switcher (Type A/B)
SCL
Memory
Trill Bar Connector
USB C
Trill Bar
I2C 0
Clock
SDA
Reset
Power
Buttons
Configure the UART in firmware for 31,250 baud, 8N1.
Optional GPIO
USB Boot Select

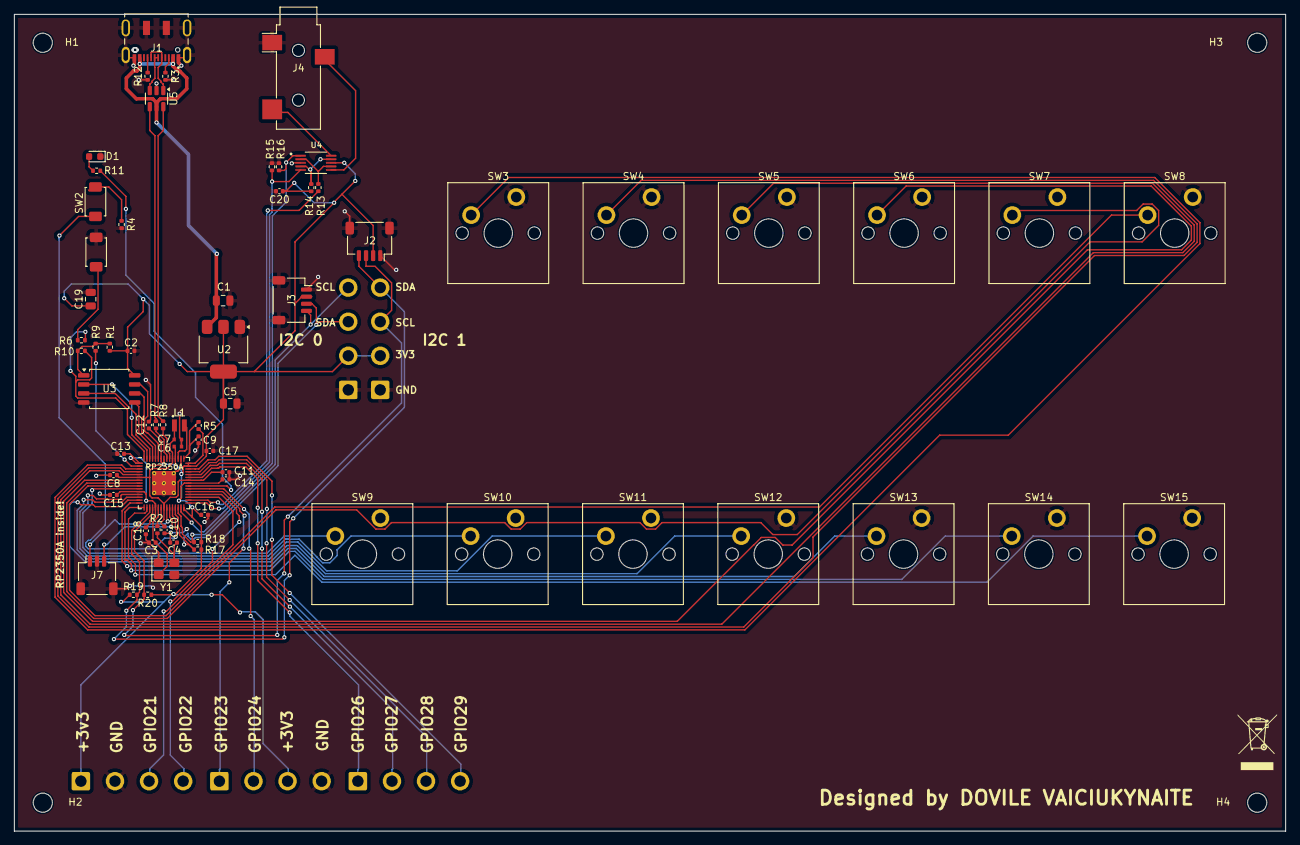
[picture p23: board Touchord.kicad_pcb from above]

Board: 2 copper layers, 179.0 x 115.0 mm, 77 parts (0 on the bottom side), 64 nets.

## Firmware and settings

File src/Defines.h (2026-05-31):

/*
 * Touchord — MIDI chord controller firmware.
 * Copyright (C) 2025-2026 MB Daugdara
 * SPDX-License-Identifier: GPL-3.0-or-later
 *
 * For more info, email info@daugdara.com
 */

#ifndef TOUCHORD_DEFINES_H
#define TOUCHORD_DEFINES_H

#define NOTE_ON  0x90
#define NOTE_OFF 0x80
#define MIDI_CHANNEL 0
#define MIDI_NOTE 60
#define MIDI_CUTOFF 74
#define MIDI_MOD 1

#define MIDI_PIN_IN_1 18
#define MIDI_PIN_IN_2 19
#define MIDI_PIN_DAT 20
#define MIDI_BAUD_RATE 31250

#define DEFAULT_CUTOFF 100

#define DEFAULT_DOUBLE_CLICK_MS 300

#ifndef TOUCHORD_DUAL_I2C
#define TOUCHORD_DUAL_I2C 1
#endif

#if TOUCHORD_DUAL_I2C
#define TRILL_I2C       i2c0
#define TRILL_PIN_SDA   16
#define TRILL_PIN_SCL   17
#define DISP_I2C        i2c1
#define DISP_PIN_SDA    14
#define DISP_PIN_SCL    15
#else
#define TRILL_I2C       i2c0
#define TRILL_PIN_SDA   16
#define TRILL_PIN_SCL   17
#define DISP_I2C        i2c0
#define DISP_PIN_SDA    16
#define DISP_PIN_SCL    17
#endif

/* Back-compat aliases for the original single-bus pin names. */
#define PIN_SDA  TRILL_PIN_SDA
#define PIN_SCL  TRILL_PIN_SCL

#define TRILL_ADDR 0x20
#define DISP_ADDR 0x3C

#define LED_PIN 25
#define CONTROL_0 1
#define CONTROL_1 2
#define CONTROL_2 3
#define CONTROL_3 4
#define CONTROL_4 5
#define CONTROL_5 6
#define NUM_CONTROLS 6
#define KEY_0 7
#define KEY_1 8
#define KEY_2 9
#define KEY_3 10
#define KEY_4 11
#define KEY_5 12
#define KEY_6 13
#define NUM_KEYS 7

#define SCALE_LEN 7
#define MAX_CHORD 6
#define CHORD_NAME_LEN 16
#define DEFAULT_OCTAVE 4
#define DEFAULT_EXTENSIONS 4
#define DEFAULT_VELOCITY 100
#define DEFAULT_INVERSION 0
#define DEFAULT_OCTAVE_COUNT 3

#define MAX_UI_DEPTH 8
#define MAX_UI_NODES 64

#endif

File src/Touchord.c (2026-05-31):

/*
 * Touchord — MIDI chord controller firmware.
 * Copyright (C) 2025-2026 MB Daugdara
 * SPDX-License-Identifier: GPL-3.0-or-later
 *
 * For more info, email info@daugdara.com
 */

#include <stdio.h>
#include <string.h>
#include "hardware/i2c.h"
#include "pico/stdlib.h"
#include "pico/multicore.h"
#include "pico/bootrom.h"
#include "pico/time.h"

#include "Defines.h"
#include "Types.h"
#include "Helper.h"
#include "Globals.h"
#include "IO/Midi.h"
#include "Data/Flash.h"
#include "Notes/Note.h"
#include "Sync.h"
#include "Rendering/Graphics.h"
#include "Rendering/ScreenDma.h"

#include "bsp/board.h"
#include "tusb.h"

#include "Modes/Compose.h"
#include "Modes/Perform.h"
#include "Modes/Strum.h"
#include "Modes/Omni.h"
#include "Modes/Drum.h"
#include "Modes/Settings.h"

void led_blinking_task(void);
static uint32_t blink_interval_ms = BLINK_NOT_MOUNTED;

void poll_buttons()
{
    uint64_t now = to_ms_since_boot(get_absolute_time());
    if (now - tc_time_last_control > DEFAULT_DOUBLE_CLICK_MS) {
        if (tc_last_control_clicks >= 2)      tc_button_double_down(tc_last_control);
        else if (tc_last_control_clicks == 1) tc_button_down(tc_last_control);
        tc_last_control_clicks = 0;
    }

    for (int i = 0; i < NUM_CONTROLS; i++) {
        bool curr_state = gpio_get(i + CONTROL_0);
        if (tc_control_states[i] && !curr_state) {
            if (tc_control_double_click[i]) {
                if (now - tc_time_last_control < DEFAULT_DOUBLE_CLICK_MS && tc_last_control == i) {
                    tc_last_control_clicks++;
                } else {
                    tc_time_last_control = now;
                    tc_last_control_clicks = 1;
                }
            } else {
                tc_button_down(i);
            }
            tc_last_control = i;
        } else if (!tc_control_states[i] && curr_state) {
            tc_button_up(i);
        }
        tc_control_states[i] = curr_state;
    }

    //B0 + B2 + B4: drop into BOOTSEL.
    if (!tc_control_states[0] && !tc_control_states[2] && !tc_control_states[4])
        tc_trigger_bootsel = true;

    for (int i = 0; i < NUM_KEYS; i++) {
        bool curr_state = gpio_get(i + KEY_0);
        if (tc_key_states[i] && !curr_state) {
            tc_key_down(i);
            tc_last_key = i;
        } else if (!tc_key_states[i] && curr_state) {
            tc_key_up(i);
            tc_key_up_independent(i);
        }
        tc_key_states[i] = curr_state;
    }
    sleep_ms(10);
}

void poll_trill_bar(TrillBar* bar)
{
    trill_read(bar);
    float pos  = trill_calculate_touch(bar);
    float size = trill_calculate_size(bar, pos);

    bool curr_state = pos >= 0.0f;
    if (curr_state) {
        const float DEAD_HIGH = 0.04f;
        pos = pos / (1.0f - DEAD_HIGH);
        if (pos > 1.0f) pos = 1.0f;

        tc_trill_pos = pos;
        tc_trill_down(pos, size);
    } else if (tc_touch_state) {
        tc_trill_up();
    }
    tc_touch_state = curr_state;
}

static void init_input_bank(int base, int count, bool *states)
{
    for (int i = 0; i < count; i++) {
        gpio_init(base + i);
        gpio_set_dir(base + i, GPIO_IN);
        gpio_pull_up(base + i);
        states[i] = true;
    }
}

void init_GPIO()
{
    init_input_bank(CONTROL_0, NUM_CONTROLS, tc_control_states);
    init_input_bank(KEY_0,     NUM_KEYS,     tc_key_states);
    gpio_init(LED_PIN);
    gpio_set_dir(LED_PIN, GPIO_OUT);
}

void init_i2c()
{
    // Trill bar's max I2C is 400 kHz
    i2c_init(TRILL_I2C, 400000);
    gpio_set_function(TRILL_PIN_SDA, GPIO_FUNC_I2C);
    gpio_set_function(TRILL_PIN_SCL, GPIO_FUNC_I2C);
    gpio_pull_up(TRILL_PIN_SDA);
    gpio_pull_up(TRILL_PIN_SCL);

#if TOUCHORD_DUAL_I2C
    // Screen owns its own bus, so push to 1 MHz
    i2c_init(DISP_I2C, 1000000);
    gpio_set_function(DISP_PIN_SDA, GPIO_FUNC_I2C);
    gpio_set_function(DISP_PIN_SCL, GPIO_FUNC_I2C);
    gpio_pull_up(DISP_PIN_SDA);
    gpio_pull_up(DISP_PIN_SCL);
#endif
}

TouchordMode prevMode = TOUCHORD_COMPOSE;

void select_mode(TouchordMode mode)
{
    switch (prevMode) {
        case TOUCHORD_COMPOSE:  compose_end();  break;
        case TOUCHORD_STRUM:    strum_end();    break;
        case TOUCHORD_PERFORM:  perform_end();  break;
        case TOUCHORD_OMNI:     omni_end();     break;
        case TOUCHORD_DRUM:     drum_end();     break;
        case TOUCHORD_SETTINGS: settings_end(); break;
    }
    switch (mode) {
        case TOUCHORD_COMPOSE:  compose_start();  break;
        case TOUCHORD_STRUM:    strum_start();    break;
        case TOUCHORD_PERFORM:  perform_start();  break;
        case TOUCHORD_OMNI:     omni_start();     break;
        case TOUCHORD_DRUM:     drum_start();     break;
        case TOUCHORD_SETTINGS: settings_start(); break;
    }
}

void io_task()
{
    multicore_lockout_victim_init();

    init_i2c();
    setup_midi_trs(tc_app.midi_type);

    tc_bar = trill_init(TRILL_I2C, TRILL_ADDR);
    trill_set_auto_scan(&tc_bar, 1);
    trill_set_noise_threshold(&tc_bar, 255);

    tc_disp.external_vcc = false;
    ssd1306_init(&tc_disp, 128, 64, DISP_ADDR, DISP_I2C);
    ssd1306_contrast(&tc_disp, 0xFF);
    screen_dma_init();

    anim_boot_intro();
    ssd1306_clear(&tc_disp);

    while (tc_running) {
        if (tc_trigger_bootsel) {
            tc_running = false;
            ssd1306_clear(&tc_disp);
            ssd1306_draw_string(&tc_disp, 10, 24, 2, "Firm Mode");
            ssd1306_show(&tc_disp);
            rom_reset_usb_boot(0, 0);
            break;
        }

        TouchordMode currentMode = tc_app_get_mode();
        if (currentMode != prevMode) {
            static uint8_t prev_fb[128 * 8];
            static uint8_t next_fb[128 * 8];
            memcpy(prev_fb, tc_disp.buffer, sizeof prev_fb);

            select_mode(currentMode);
            ssd1306_clear(&tc_disp);
            tc_draw();
            memcpy(next_fb, tc_disp.buffer, sizeof next_fb);

            int direction = (currentMode == TOUCHORD_SETTINGS || prevMode == TOUCHORD_SETTINGS)
                            ? 0
                            : (currentMode > prevMode ? 1 : -1);

            anim_transition(prev_fb, next_fb, direction);
            prevMode = currentMode;
            continue;
        }

        ssd1306_clear(&tc_disp);
        tc_draw();
        tc_update();
        draw_trill_indicator();
        draw_overlay();

#if TOUCHORD_DUAL_I2C
        screen_show_async(&tc_disp);
        do {
            poll_trill_bar(&tc_bar);
        } while (screen_show_busy());
        screen_show_wait();
#else
        for (int i = 0; i < 5; i++) poll_trill_bar(&tc_bar);
        ssd1306_show(&tc_disp);
#endif
    }
}

int main()
{
    board_init();
    init_GPIO();
    sleep_ms(500);

    if (!gpio_get(CONTROL_0))
        rom_reset_usb_boot(0, 0);

    tc_app = tc_app_default;
    tc_app_working = tc_app_default;
    flash_load_preset(0, &tc_app);
    // Always boot into Compose
    tc_app.mode = TOUCHORD_COMPOSE;

    tc_sync_init();
    reload_custom_scales();
    compose_start();

    tud_init(0);
    multicore_launch_core1(io_task);

    while (true) {
        tud_task();
        if (tud_midi_mounted()) poll_buttons();
        led_blinking_task();
    }
}

void tud_mount_cb(void)               { blink_interval_ms = BLINK_MOUNTED; }
void tud_umount_cb(void)              { blink_interval_ms = BLINK_NOT_MOUNTED; }
void tud_suspend_cb(bool remote)      { (void)remote; blink_interval_ms = BLINK_SUSPENDED; }
void tud_resume_cb(void)              { blink_interval_ms = BLINK_MOUNTED; }

void led_blinking_task(void)
{
    static uint32_t start_ms = 0;
    static bool led_state = false;

    if (board_millis() - start_ms < blink_interval_ms) return;
    start_ms += blink_interval_ms;

    board_led_write(led_state);
    led_state = !led_state;
}

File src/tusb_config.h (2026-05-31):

/*
 * Touchord — MIDI chord controller firmware.
 * Copyright (C) 2025-2026 MB Daugdara
 * SPDX-License-Identifier: GPL-3.0-or-later
 *
 * For more info, email info@daugdara.com
 */


#ifndef _TUSB_CONFIG_H_
#define _TUSB_CONFIG_H_

#ifdef __cplusplus
extern "C" {
#endif

//--------------------------------------------------------------------
// COMMON CONFIGURATION
//--------------------------------------------------------------------

// defined by compiler flags for flexibility
#ifndef CFG_TUSB_MCU
#error CFG_TUSB_MCU must be defined
#endif

#if CFG_TUSB_MCU == OPT_MCU_LPC18XX || CFG_TUSB_MCU == OPT_MCU_LPC43XX || CFG_TUSB_MCU == OPT_MCU_MIMXRT10XX || \
    CFG_TUSB_MCU == OPT_MCU_NUC505 || CFG_TUSB_MCU == OPT_MCU_CXD56
#define CFG_TUSB_RHPORT0_MODE     (OPT_MODE_DEVICE | OPT_MODE_HIGH_SPEED)
#else
#define CFG_TUSB_RHPORT0_MODE     OPT_MODE_DEVICE
#endif

#ifndef CFG_TUSB_OS
#define CFG_TUSB_OS                 OPT_OS_PICO
#endif

// CFG_TUSB_DEBUG is defined by compiler in DEBUG build
// #define CFG_TUSB_DEBUG           0

/* USB DMA on some MCUs can only access a specific SRAM region with restriction on alignment.
 * Tinyusb use follows macros to declare transferring memory so that they can be put
 * into those specific section.
 * e.g
 * - CFG_TUSB_MEM SECTION : __attribute__ (( section(".usb_ram") ))
 * - CFG_TUSB_MEM_ALIGN   : __attribute__ ((aligned(4)))
 */
#ifndef CFG_TUSB_MEM_SECTION
#define CFG_TUSB_MEM_SECTION
#endif

#ifndef CFG_TUSB_MEM_ALIGN
#define CFG_TUSB_MEM_ALIGN          __attribute__ ((aligned(4)))
#endif

//--------------------------------------------------------------------
// DEVICE CONFIGURATION
//--------------------------------------------------------------------

#ifndef CFG_TUD_ENDPOINT0_SIZE
#define CFG_TUD_ENDPOINT0_SIZE    64
#endif

//------------- CLASS -------------//
#define CFG_TUD_CDC             1
#define CFG_TUD_MSC             0
#define CFG_TUD_HID             0 
#define CFG_TUD_MIDI            1 
#define CFG_TUD_VENDOR          0

#define CFG_TUH_CABLE_MAX 6

// MIDI FIFO size of TX and RX
#define CFG_TUD_MIDI_RX_BUFSIZE   (TUD_OPT_HIGH_SPEED ? 512 : 64)
#define CFG_TUD_MIDI_TX_BUFSIZE   (TUD_OPT_HIGH_SPEED ? 512 : 64)

#define CFG_TUD_CDC_RX_BUFSIZE   (TUD_OPT_HIGH_SPEED ? 512 : 256)
#define CFG_TUD_CDC_TX_BUFSIZE   (TUD_OPT_HIGH_SPEED ? 512 : 256)

#ifdef __cplusplus
}
#endif



#endif

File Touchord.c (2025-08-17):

#include <stdio.h>
#include "hardware/i2c.h"
#include "pico/stdlib.h"
#include "pico/binary_info.h"
#include "pico/multicore.h"
#include "Defines.h"
#include "Types.h"
#include "Helper.h"

#include "Notes/Note.h"
#include "Midi.h"

#include "bsp/board.h"
#include "tusb.h"

#include "Trill.h"
#include "ssd1306.h"


TouchordData appData = 
{
    {{"C", "min"}, {"E", "min"}, {"D", "maj"}}, 0,
    4, 4, 0, 100, 
    TOUCHORD_COMPOSE, 1, 0,
    {0, 0, 0, 0, 0, 0}, {'\0'}
};



void led_blinking_task(void);

static uint32_t blink_interval_ms = BLINK_NOT_MOUNTED;
bool button_states[NUM_BUTTONS];
bool control_states[NUM_CONTROLS];

void poll_buttons()
{
    for (int i = 3; i < NUM_CONTROLS; i++)
    {   
        bool curr_state = gpio_get(i + CONTROL_0);
        if(!control_states[i] && curr_state)
        {
            appData.current_key = i-3;
        }
        control_states[i] = curr_state;
    }

    for (int i = 0; i < NUM_BUTTONS; i++)
    {   
        bool curr_state = gpio_get(i + BUTTON_0);
        if(button_states[i] && !curr_state)
        {
            send_midi_chord(NOTE_OFF, appData.chord, appData.extension_count, appData.velocity);
            build_chord(appData.key[appData.current_key], appData.octave, i, CHORD_DEFAULT, 
                        appData.extension_count, appData.inversion, appData.chord, appData.chord_name);
            send_midi_chord(NOTE_ON, appData.chord, appData.extension_count, appData.velocity);
        }
        else if(!button_states[i] && curr_state)
        {
            send_midi_chord(NOTE_OFF, appData.chord, appData.extension_count, appData.velocity);
            build_chord(appData.key[appData.current_key], appData.octave, 0, CHORD_DEFAULT, 
                        0, appData.inversion, appData.chord, appData.chord_name);
            appData.chord_name[0] = '\0';
        }
        button_states[i] = curr_state;
    }
    sleep_ms(10);
}

void init_buttons()
{
    for (int i = 0; i < NUM_CONTROLS; i++)
    {
        gpio_init(i + CONTROL_0);
        gpio_set_dir(i + CONTROL_0, GPIO_IN);
        gpio_pull_up(i + CONTROL_0);

        control_states[i] = true;
      }

    for (int i = 0; i < NUM_BUTTONS; i++)
    {
        gpio_init(i + BUTTON_0);
        gpio_set_dir(i + BUTTON_0, GPIO_IN);
        gpio_pull_up(i + BUTTON_0);
        button_states[i] = true;
    }
}

void init_i2c()
{
    i2c_init(i2c0, 100000);

    gpio_set_function(PIN_SDA, GPIO_FUNC_I2C);
    gpio_set_function(PIN_SCL, GPIO_FUNC_I2C);

    gpio_pull_up(PIN_SDA);
    gpio_pull_up(PIN_SCL);
}


void io_task()
{
    init_i2c();
    ssd1306_t disp;
    disp.external_vcc = false;
    ssd1306_init(&disp, 128, 64, 0x3C, i2c0);
    ssd1306_clear(&disp);
    
    gpio_init(LED_PIN);
    gpio_set_dir(LED_PIN, GPIO_OUT);

    TrillBar bar = trill_init(i2c0, TRILL_ADDR);
    trill_set_noise_threshold(&bar, 255);

    uint8_t count = 0;
    Touch touches[TRILL_MAX_TOUCHES];

    while(true)
    {
        ssd1306_clear(&disp);

        ssd1306_draw_string(&disp, 8, 24, 2, appData.chord_name);

        ssd1306_draw_string(&disp, 0, 0, 1, "Key: ");
        ssd1306_draw_string(&disp, 26, 0, 1, appData.key[appData.current_key].root);
        ssd1306_draw_string(&disp, 38, 0, 1, appData.key[appData.current_key].quality);
        
        trill_read(&bar);
        Touch touches[TRILL_MAX_TOUCHES];
        
        trill_touches(&bar, touches, &count);
        for(int i = 0; i < count; i++)
        {
            char buf[32];
            sprintf(buf, "%f, %f", touches[i].pos, touches[i].size);
            ssd1306_draw_string(&disp, 0, (i+1) * 10, 1, buf);
        }
        
        ssd1306_show(&disp);
    }
}

int main()
{
    board_init();
    sleep_ms(2000);
    tud_init(0);

    init_buttons();
    multicore_launch_core1(io_task);

    while (true) {
        tud_task();
        if (tud_midi_mounted()) 
        {
            poll_buttons();
        }
        led_blinking_task();
    }
}

void tud_mount_cb(void)
{
  blink_interval_ms = BLINK_MOUNTED;
}

void tud_umount_cb(void)
{
  blink_interval_ms = BLINK_NOT_MOUNTED;
}

void tud_suspend_cb(bool remote_wakeup_en)
{
  (void) remote_wakeup_en;
  blink_interval_ms = BLINK_SUSPENDED;
}

void tud_resume_cb(void)
{
  blink_interval_ms = BLINK_MOUNTED;
}

void led_blinking_task(void)
{
  static uint32_t start_ms = 0;
  static bool led_state = false;

  // Blink every interval ms
  if ( board_millis() - start_ms < blink_interval_ms) return; // not enough time
  start_ms += blink_interval_ms;

  board_led_write(led_state);
  led_state = 1 - led_state; // toggle
}

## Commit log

2025-08-05 TUSB Midi device, initial refactoring
2025-08-17 Imported Display driver, wrote a Trill bar driver
2025-08-28 Fixed trill driver precision errors
    [Defines.h, Midi.c, Touchord.c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]
2025-09-07 Cleanup, Modularity, Working prototype
2025-09-14 General fixes, TRS MIDI support
    [Defines.h, Midi.c, Touchord.c]
2025-09-30 Fixed some bugs, added Web Settings Editor
    [Defines.h, Midi.c]
2025-10-23 Added Schematic
2025-11-09 Fixed Omni Mode
    Adjusted Omni mode to mimic Omnichord
    [Touchord.c, Trill.h]
2025-12-29 Added work-in-progress enclosures
    [1ux6 plate.stl, 3D Printed Top.stl, 3ux7 plate.stl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]
2026-05-31 Added New Enclosures.
    [1U Keycap.step, 1ux6 plate.stl, 3D Printed Top.stl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]
2026-05-31 Release v1.0.0
    First tagged release. Highlights:
    - Compose mode with Jazz substitutions, voice-leading, trill tooltip.
    - Drum mode with 7-pad grid.
    - Strum / Omni / Perform / Settings modes; transitions between all.
    - Persistent presets (8 slots), four custom scales, MIDI channel /
    velocity / TRS-type configuration.
    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
2026-07-21 Added KiCad files
    [Touchord.kicad_pcb, Touchord.kicad_sch]
